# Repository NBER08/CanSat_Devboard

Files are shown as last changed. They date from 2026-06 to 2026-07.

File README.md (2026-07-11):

<p align="center" width="100%">
  
</p>

<h1 align="center">CanSat Devboard</h1>

<p align="center" width="100%">
  <a href="https://github.com/nguyen-v/KDT_Hierarchical_KiBot/actions/workflows/ci.yaml">
    
  </a>
</p>

<p align="center" width="100%">
    
</p>

***

<p align="center">
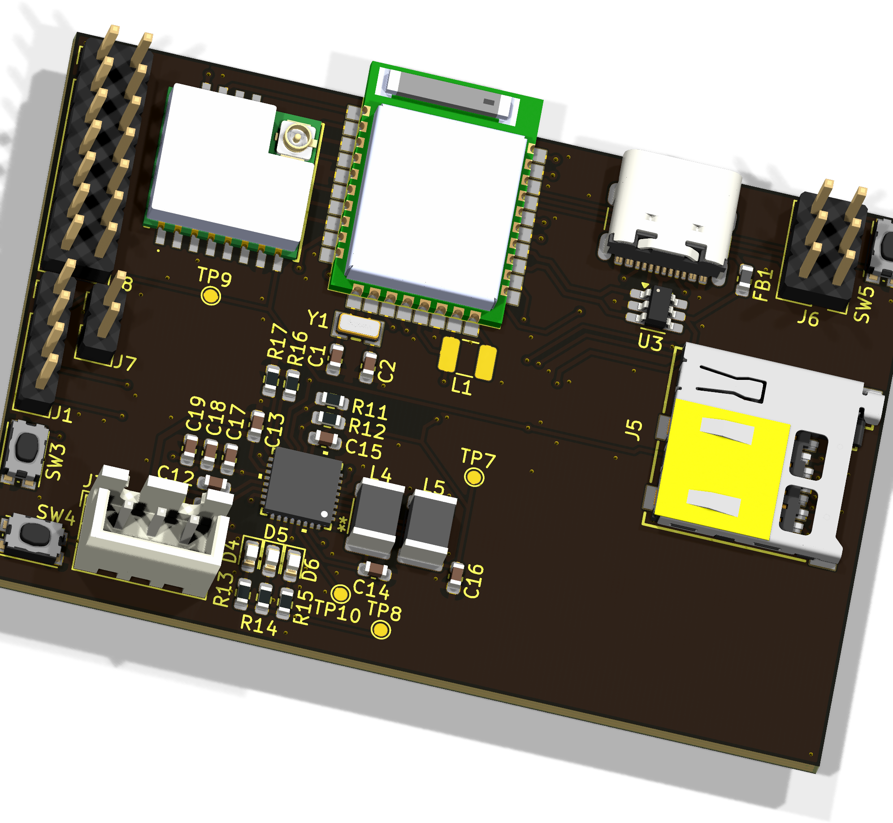
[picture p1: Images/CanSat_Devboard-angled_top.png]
3D Top Angled
  
&nbsp; &nbsp; &nbsp; &nbsp;
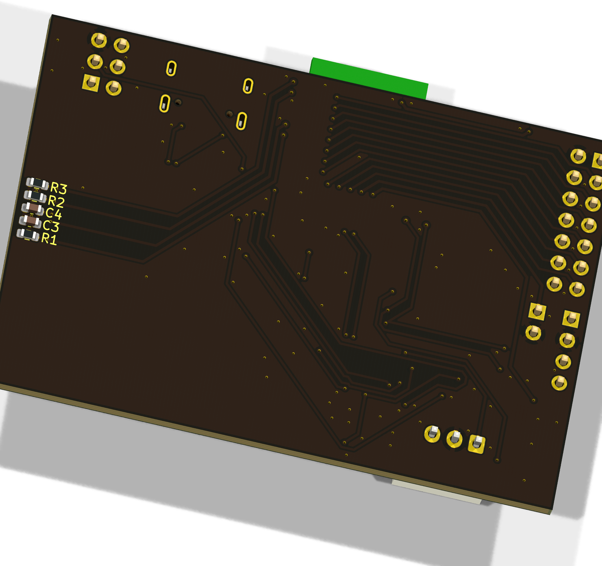
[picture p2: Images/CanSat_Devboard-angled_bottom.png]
3D Bottom Angled
  
</p>

***

## SPECIFICATIONS

| Parameter | Value | 
| --- | --- |
| Dimensions | 64.06 × 43.56 mm |

***

## DIRECTORY STRUCTURE

    .
    ├─ Computations       # Misc calculations
    ├─ HTML               # HTML files for generated webpage
    ├─ Images             # Pictures and renders
    │
    ├─ kibot_resources    # External resources for KiBot
    │  ├─ colors          # Color theme for KiCad
    │  ├─ fonts           # Fonts used in the project
    │  ├─ scripts         # External scripts used with KiBot
    │  └─ templates       # Templates for KiBot generated reports
    │
    ├─ kibot_yaml         # KiBot YAML config files
    ├─ KiRI               # KiRI (PCB diff viewer) files
    │
    ├─ lib                # KiCad footprint and symbol libraries
    │  ├─ 3d_models       # Component 3D models
    │  ├─ lib_fp          # Footprint libraries
    │  └─ lib_sym         # Symbol libraries
    │
    ├─ Logos              # Logos
    │
    ├─ Manufacturing      # Assembly and fabrication documents
    │  ├─ Assembly        # Assembly documents (BoM, pos, notes)
    │  │
    │  └─ Fabrication     # Fabrication documents (ZIP, notes)
    │     ├─ Drill Tables # CSV drill tables
    │     └─ Gerbers      # Gerbers
    │
    ├─ Report             # Reports for ERC/DRC
    ├─ Schematic          # PDF of schematic
    ├─ Templates          # Title block templates
    ├─ Testing
    │  └─ Testpoints      # Testpoints tables      
    │
    └─ Variants           # Outputs for assembly variants

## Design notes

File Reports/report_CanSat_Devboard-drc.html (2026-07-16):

Logo

(https://github.com/INTI-CMNB/KiBot/) | DRC report for CanSat_Devboard
| PCB: CanSat_Devboard Revision: + (Unreleased) Date: 2026-07-16T17:37:52 KiCad Version: 10.0.4 | Errors: 0 Warnings: 0 (+4 excluded) Total: 0 (+4 excluded)

✔

Violations

Type | Description | Details
lib_footprint_mismatch | Footprint 'USB_C_Receptacle_GCT_USB4105-xx-A_16P_TopMnt_Horizontal' does not match copy in library 'Connector_USB' | @(162.7248 mm, 81.5314 mm): Footprint J4
silk_edge_clearance | Silkscreen clipped by board edge | @(116.9794 mm, 77.3912 mm): Rectangle on Edge.Cuts @(138.775 mm, 74.3174 mm): Segment of U1 on F.Silkscreen
silk_edge_clearance | Silkscreen clipped by board edge | @(116.9794 mm, 77.3912 mm): Rectangle on Edge.Cuts @(151.775 mm, 92.8174 mm): Segment of U1 on F.Silkscreen

Schematic parity

Type | Description | Details
net_conflict | No pad found for pin S1 (GND) in schematic | @(162.7248 mm, 81.5314 mm): Footprint J4

Generated by KiBot (https://github.com/INTI-CMNB/KiBot/) v1.9.1

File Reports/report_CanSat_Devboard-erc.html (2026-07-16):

Logo

(https://github.com/INTI-CMNB/KiBot/) | ERC report for CanSat_Devboard
| Schematic: CanSat_Devboard Revision: + (Unreleased) Date: 2026-07-16T17:37:47 KiCad Version: 10.0.4 | Errors: 0 Warnings: 4 (+2 excluded) Total: 4 (+2 excluded)

Sheet / (CanSat_Devboard.kicad_sch)

Type | Description | Details
footprint_link_issues | The current configuration does not include the footprint library 'E73-2G4M08S1C' | @(0.508 mm, 1.4224 mm): Symbol U1 [E73-2G4M08S1C]
footprint_link_issues | The current configuration does not include the footprint library 'E73-2G4M08S1C' | @(0.5588 mm, 0.9017 mm): Symbol U1 [E73-2G4M08S1C]
footprint_link_issues | The current configuration does not include the footprint library 'E73-2G4M08S1C' | @(1.5113 mm, 0.6858 mm): Symbol U1 [E73-2G4M08S1C]
lib_symbol_mismatch | Symbol doesn't match copy in library | @(1.143 mm, 0.9652 mm): Symbol J4 [USB_C_Receptacle_USB2.0_16P]

Sheet /Project Architecture/Power/ (Power.kicad_sch)

Type | Description | Details
multiple_net_names | Both VSYS and PVDD are attached to the same items; VSYS will be used in the netlist | @(1.2065 mm, 1.3462 mm): Symbol #PWR063 Pin 1 [Power input, Line] @(0.6096 mm, 1.0922 mm): Label 'PVDD'
multiple_net_names | More than one name given to this bus or net | @(2.2352 mm, 0.7366 mm): Symbol #PWR056 Pin 1 [Power input, Line] @(0.6096 mm, 1.0922 mm): Label 'PVDD'

Generated by KiBot (https://github.com/INTI-CMNB/KiBot/) v1.9.1

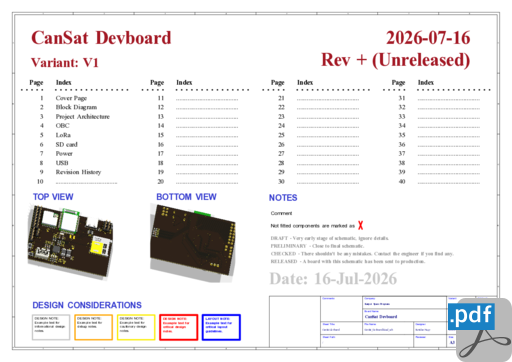
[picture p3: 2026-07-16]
HTML/images/cat_pdf_schematic_CanSat_Devboard-schematic.png

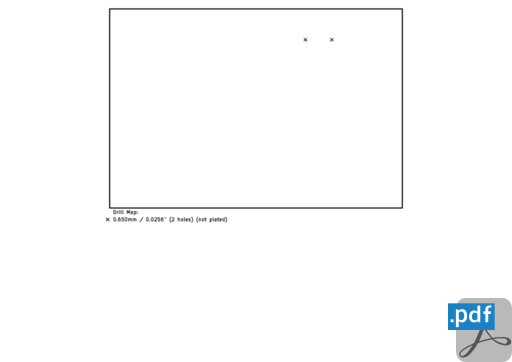
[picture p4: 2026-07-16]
HTML/images/cat_pdf_drill_map_CanSat_Devboard-NPTH_drill_map.png

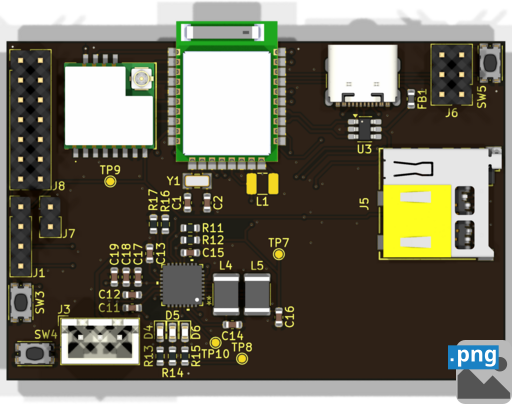
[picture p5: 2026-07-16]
HTML/images/cat_png_3d_viewer_top_CanSat_Devboard-top.png

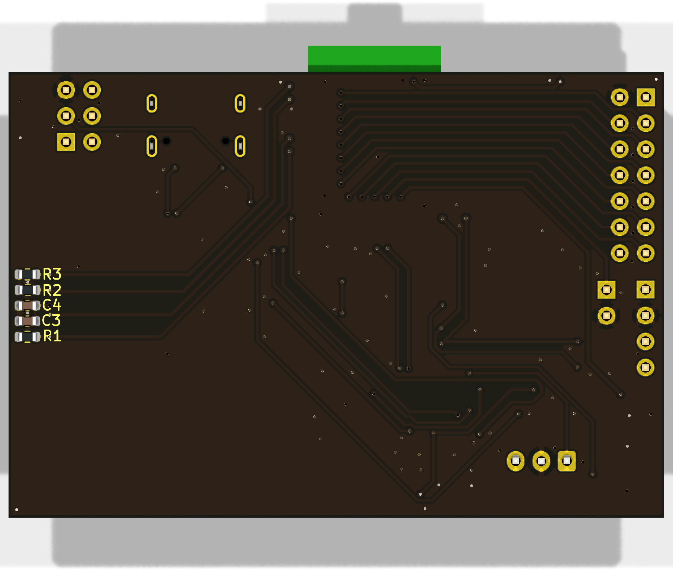
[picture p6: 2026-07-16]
Images/CanSat_Devboard-bottom.png

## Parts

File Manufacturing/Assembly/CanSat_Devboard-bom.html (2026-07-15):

 | Bill of Materials
 | Schematic: CanSat_Devboard Variant: CHECKED Revision: + (Unreleased) Date: 2026-07-05 KiCad Version: 10.0.4-10.0.4~ubuntu25.10.1 | Component Groups: 24 Component Count: 44 (per PCB) Fitted Components: 44 (per PCB) Number of PCBs: 1 Total Components: 44 (for 1 PCBs)
Row | Quantity Per PCB | References | Value | Datasheet | Footprint | Description | Manufacturer | Manufacturer Part Number | Supplier Part Number
1 | 2 | C1 C2 | 22p |  | C_0603_1608Metric | Unpolarized capacitor
2 | 2 | C3 C15 | 0.1u |  | C_0603_1608Metric | Unpolarized capacitor
3 | 2 | C11 C12 | 1u |  | C_0603_1608Metric | Unpolarized capacitor
4 | 3 | C13 L4 L5 | 2u2 |  | C_0603_1608Metric | Unpolarized capacitor Inductor, small symbol
5 | 6 | C4 C14 C16 C17 C18 C19 | 10u |  | C_0603_1608Metric | Unpolarized capacitor
6 | 1 | D4 | Amber |  | LED_0603_1608Metric | Light emitting diode, small symbol
7 | 1 | D6 | Blue |  | LED_0603_1608Metric | Light emitting diode, small symbol
8 | 1 | D5 | Green |  | LED_0603_1608Metric | Light emitting diode, small symbol
9 | 1 | FB1 | LI0603G121R-10 |  | L_0603_1608Metric | Ferrite bead
10 | 1 | IC1 | 114993390 |  | 114993390 | RF Modules Wio-SX1262 Wireless Module (Bulk), SX1262 embedded, supports LoRa&LoRaWAN on EU868 & US915
11 | 1 | J5 | 693071010811 |  | 693071010811 | 693 Series, Header for use with Micro SD Card | Wurth Electronics 693071010811
12 | 6 | J1 J3 J4 J6 J7 J8 | I2C |  | PinHeader_1x04_P2.54mm_Vertical | Generic connector, single row, 01x04, script generated Generic connector, single row, 01x03, script generated USB 2.0-only 16P Type-C Receptacle connector Generic connector, single row, 01x02, script generated Generic connector, double row, 02x07, odd/even pin numbering scheme (row 1 odd numbers, row 2 even numbers), script generated (kicad-library-utils/schlib/autogen/connector/)
13 | 2 | R14 R15 | 180 |  | R_0603_1608Metric | Resistor, small symbol
14 | 1 | R13 | 310 |  | R_0603_1608Metric | Resistor, small symbol
15 | 2 | R11 R12 | 4k7 |  | R_0603_1608Metric | Resistor
16 | 4 | R1 R2 R3 R17 | 47k |  | R_0603_1608Metric | Resistor
17 | 1 | R16 | 150k |  | R_0603_1608Metric | Resistor
18 | 1 | SW5 | RST |  | SW_Push_1P1T_NO_CK_KMR2 | Push button switch, generic, two pins
19 | 1 | SW4 | SHPHLD |  | SW_Push_1P1T_NO_CK_KMR2 | Push button switch, generic, two pins
20 | 1 | SW3 | SW_Push |  | SW_Push_1P1T_NO_CK_KMR2 | Push button switch, generic, two pins
21 | 1 | U1 | E73-2G4M08S1C |  | E73-2G4M08S1C | nRF52840 2.4GHZ SMD Wireless Module
22 | 1 | U4 | NPM1300-QEAA-R7 | https://docs.nordicsemi.com/viewer/book-attachment/kL6EnWEP1WN7P3ZfxvlurA/GH9B8FbYdmCpdjRokvIB_w-kL6EnWEP1WN7P3ZfxvlurA | QFN32_5X5_NOR
23 | 1 | U3 | SRV05-4 | http://www.onsemi.com/pub/Collateral/SRV05-4-D.PDF | SOT-23-6_Handsoldering | ESD Protection Diodes with Low Clamping Voltage, SOT-23-6
24 | 1 | Y1 | 32.768 |  | WE-XTAL_CFPX-217 | 32.768 kHz ±20ppm Crystal 12.5pF 70 kOhms 2-SMD, No Lead
Color reference for columns:
KiCad Fields (default)
Generated Fields
User Fields
Empty Fields

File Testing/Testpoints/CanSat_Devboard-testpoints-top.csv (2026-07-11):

Ref. | Net | X [mm] | Y [mm]
TP7 | VMCU | 87.96 | 1.25
TP8 | VSYS | 83.23 | -12.16
TP9 | +3.3V | 66.31 | 10.60
TP10 | VLDO | 79.83 | -10.12

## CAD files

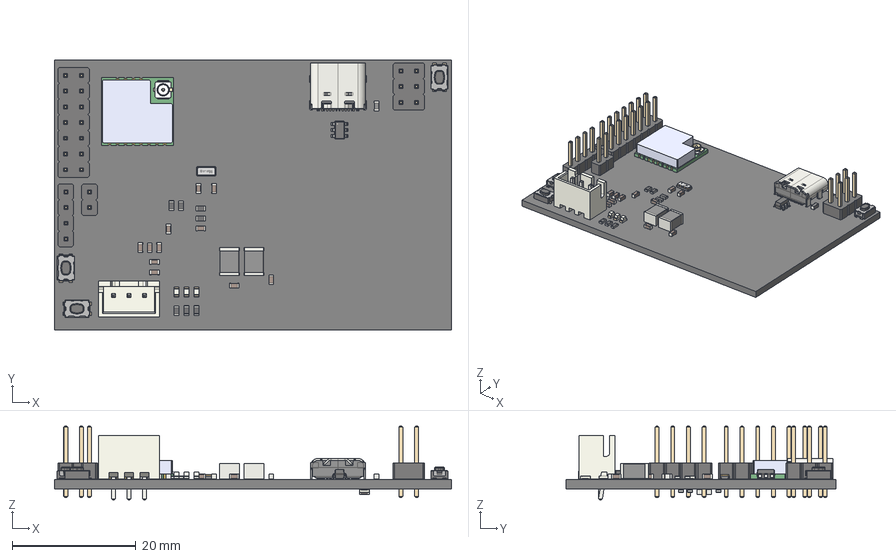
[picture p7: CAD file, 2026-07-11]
3D/CanSat_Devboard.step
64.1 x 43.6 x 11.9 mm
Pins
Cover
L_1812_4532Metric x 2
C_0603_1608Metric x 13
R_0603_1608Metric x 10
SOT-23-6
PinHeader_2x07_P254mm_Vertical
USB_C_Receptacle_16P_TopMnt_Horizontal_GCT_USB4105-xx-A
User_Library-IPEX
Extruded
LED_0603_1608Metric x 3
JST_B3B_XH_A
L_0603_1608Metric
SW_Push_1P1T_NO_CK_KMR2 x 3
PinHeader_1x04_P254mm_Vertical
PinHeader_1x02_P254mm_Vertical
PinHeader_2x03_P254mm_Vertical
kibot_y3b886p5_PCB

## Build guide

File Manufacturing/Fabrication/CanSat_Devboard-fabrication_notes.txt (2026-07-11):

FABRICATION NOTES (UNLESS OTHERWISE SPECIFIED)

1)	FABRICATE PER IPC-6012A CLASS 2.

2)	OUTLINE DEFINED IN SEPARATE GERBER FILE WITH
	"Edge_Cuts.GBR" SUFFIX.

	DIMENSIONS OF CIRCUMSIZED RECTANGLE SHOWN ON THIS
	DRAWING FOR REFERENCE ONLY.

3)	SEE SEPARATE DRILL FILES WITH ".DRL" SUFFIX 
	FOR HOLE LOCATIONS.

	SELECTED HOLE LOCATIONS SHOWN ON THIS DRAWING 
	FOR REFERENCE ONLY.

4)	SURFACE FINISH: IMMERSION GOLD

5)	SOLDERMASK ON BOTH SIDES OF THE BOARD SHALL 
	BE LPI, COLOR BLACK.

6)	SILK SCREEN LEGEND TO BE APPLIED PER LAYER 
	STACKUP USING YELLOW NON-CONDUCTIVE EPOXY INK.

7)	ALL VIAS ARE TENTED ON BOTH SIDES UNLESS 
	SOLDERMASK OPENED IN GERBER.

8)	VENDOR SHOULD FOLLOW ROHS COMPLIANT PROCESS 
	AND Pb FREE FOR MANUFACTURING

9)	PCB MATERIAL REQUIREMENTS:

	A.	FLAMMABILITY RATING MUST MEET OR EXCEED 
		UL94V-0 REQUIREMENTS.
	B.	Tg 170 C OR EQUIVALENT.
	C.	EQUIVALENT MATERIAL SHALL BE RoHS COMPLIANT, 
		HALOGEN FREE AND APPROVED BY KARPAT SPACE PROGRAM.

10)	DESIGN GEOMETRY MINIMUM FEATURE SIZES:

	BOARD SIZE				64.059 × 43.561 mm
	BOARD THICKNESS		1.660 mm
	TRACE WIDTH			0.200 mm
	TRACE TO TRACE		0.200 mm
	MIN. HOLE (PTH)			0.250 mm
	MIN. HOLE (NPTH)		0.650 mm
	ANNULAR RING			0.150 mm
	COPPER TO HOLE		0.250 mm
	COPPER TO EDGE		0.250 mm
	HOLE TO HOLE			0.100 mm

11)	REFER TO IMPEDANCE TABLE FOR IMPEDANCE CONTROL REQUIREMENTS.

12)	CONFIRM SPACE WIDTHS AND SPACINGS.

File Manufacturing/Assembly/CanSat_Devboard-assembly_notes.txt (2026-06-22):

ASSEMBLY NOTES (UNLESS OTHERWISE SPECIFIED)

1)	DO NOT POPULATE PARTS ARE MARKED WITH A RED CROSS.

2)	DO NOT POPULATE PARTS ARE NOT PRESENT IN THE BOM.

3)	IF CONFLICTING INFORMATION IS FOUND BETWEEN THE ASSEMBLY
	FILE AND BOM, BOM SHOULD BE USED AS THE MAIN SOURCE.

4)	CONFORMAL COATING IS NOT REQUIRED.

5)	DOT IDENTIFIES PIN #1 LOCATION AND DEVICE ORIENTATION
	WHEN VIEWED FROM THE TOP.

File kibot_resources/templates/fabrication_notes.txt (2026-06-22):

FABRICATION NOTES (UNLESS OTHERWISE SPECIFIED)

1)	FABRICATE PER IPC-6012A CLASS 2.

2)	OUTLINE DEFINED IN SEPARATE GERBER FILE WITH
	"Edge_Cuts.GBR" SUFFIX.

	DIMENSIONS OF CIRCUMSIZED RECTANGLE SHOWN ON THIS
	DRAWING FOR REFERENCE ONLY.

3)	SEE SEPARATE DRILL FILES WITH ".DRL" SUFFIX 
	FOR HOLE LOCATIONS.

	SELECTED HOLE LOCATIONS SHOWN ON THIS DRAWING 
	FOR REFERENCE ONLY.

4)	SURFACE FINISH: ${pcb_finish_cap}

5)	SOLDERMASK ON BOTH SIDES OF THE BOARD SHALL 
	BE LPI, COLOR ${solder_mask_color_text_cap}.

6)	SILK SCREEN LEGEND TO BE APPLIED PER LAYER 
	STACKUP USING ${silk_screen_color_text_cap} NON-CONDUCTIVE EPOXY INK.

7)	ALL VIAS ARE TENTED ON BOTH SIDES UNLESS 
	SOLDERMASK OPENED IN GERBER.

8)	VENDOR SHOULD FOLLOW ROHS COMPLIANT PROCESS 
	AND Pb FREE FOR MANUFACTURING

9)	PCB MATERIAL REQUIREMENTS:

	A.	FLAMMABILITY RATING MUST MEET OR EXCEED 
		UL94V-0 REQUIREMENTS.
	B.	Tg 170 C OR EQUIVALENT.
	C.	EQUIVALENT MATERIAL SHALL BE RoHS COMPLIANT, 
		HALOGEN FREE AND APPROVED BY ${COMPANY_cap}.

10)	DESIGN GEOMETRY MINIMUM FEATURE SIZES:

	BOARD SIZE				${bb_w_mm} × ${bb_h_mm} mm
	BOARD THICKNESS		${thickness_mm} mm
	TRACE WIDTH			${track_mm} mm
	TRACE TO TRACE		${clearance_mm} mm
	MIN. HOLE (PTH)			${drill_pth_real_mm} mm
	MIN. HOLE (NPTH)		${drill_npth_real_mm} mm
	ANNULAR RING			${oar_mm} mm
	COPPER TO HOLE		${c2h_mm} mm
	COPPER TO EDGE		${c2e_mm} mm
	HOLE TO HOLE			${h2h_mm} mm
#?stackup and impedance_controlled

#?stackup and impedance_controlled
11)	REFER TO IMPEDANCE TABLE FOR IMPEDANCE CONTROL REQUIREMENTS.
#?stackup and impedance_controlled

#?stackup and impedance_controlled
12)	CONFIRM SPACE WIDTHS AND SPACINGS.

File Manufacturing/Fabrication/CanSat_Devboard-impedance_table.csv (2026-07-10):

Transmission Line | Impedance [ohms] | Tolerance [ohms] | Layer | Trace Width [mm] | Gap [mm] | Ref. Layers
Edge-Coupled Coated Microstrip | 100 | ±10 % | L1 | 0.2032 | 0.28 | L2

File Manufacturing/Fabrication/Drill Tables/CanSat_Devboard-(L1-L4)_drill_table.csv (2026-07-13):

Count | Hole Size | Plated | Hole Shape | Drill Layer Pair | Hole Type
145 | 0.25mm (9.84mils) | PTH | Round | L1 (Sig, PWR) - L4 (Sig, PWR) | Via
6 | 0.30mm (11.81mils) | PTH | Round | L1 (Sig, PWR) - L4 (Sig, PWR) | Via
4 | 0.60mm (23.62mils) | PTH | Slot | L1 (Sig, PWR) - L4 (Sig, PWR) | Pad
3 | 0.95mm (37.40mils) | PTH | Round | L1 (Sig, PWR) - L4 (Sig, PWR) | Pad
26 | 1.00mm (39.37mils) | PTH | Round | L1 (Sig, PWR) - L4 (Sig, PWR) | Pad
Total 184

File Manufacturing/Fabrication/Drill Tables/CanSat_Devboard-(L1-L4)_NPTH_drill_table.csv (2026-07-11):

Count | Hole Size | Plated | Hole Shape | Drill Layer Pair | Hole Type
2 | 0.65mm (25.59mils) | NPTH | Round | L1 (Sig, PWR) - L4 (Sig, PWR) | Mechanical
Total 2

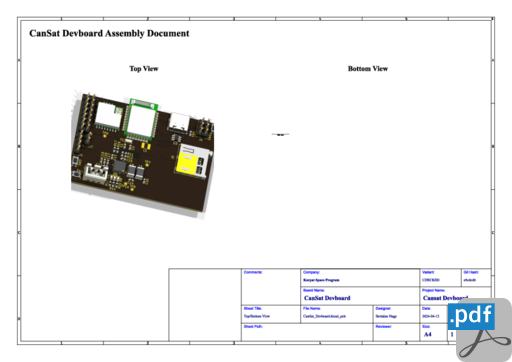
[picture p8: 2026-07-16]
HTML/images/cat_pdf_assembly_CanSat_Devboard-assembly.png

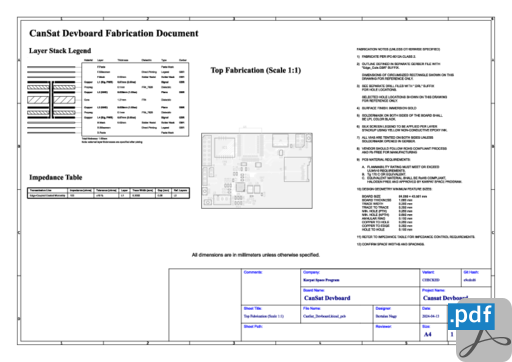
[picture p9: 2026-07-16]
HTML/images/cat_pdf_fabrication_CanSat_Devboard-fabrication.png

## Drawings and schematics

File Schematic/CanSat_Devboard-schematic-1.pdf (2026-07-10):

# CanSat Devboard

# Variant: V1

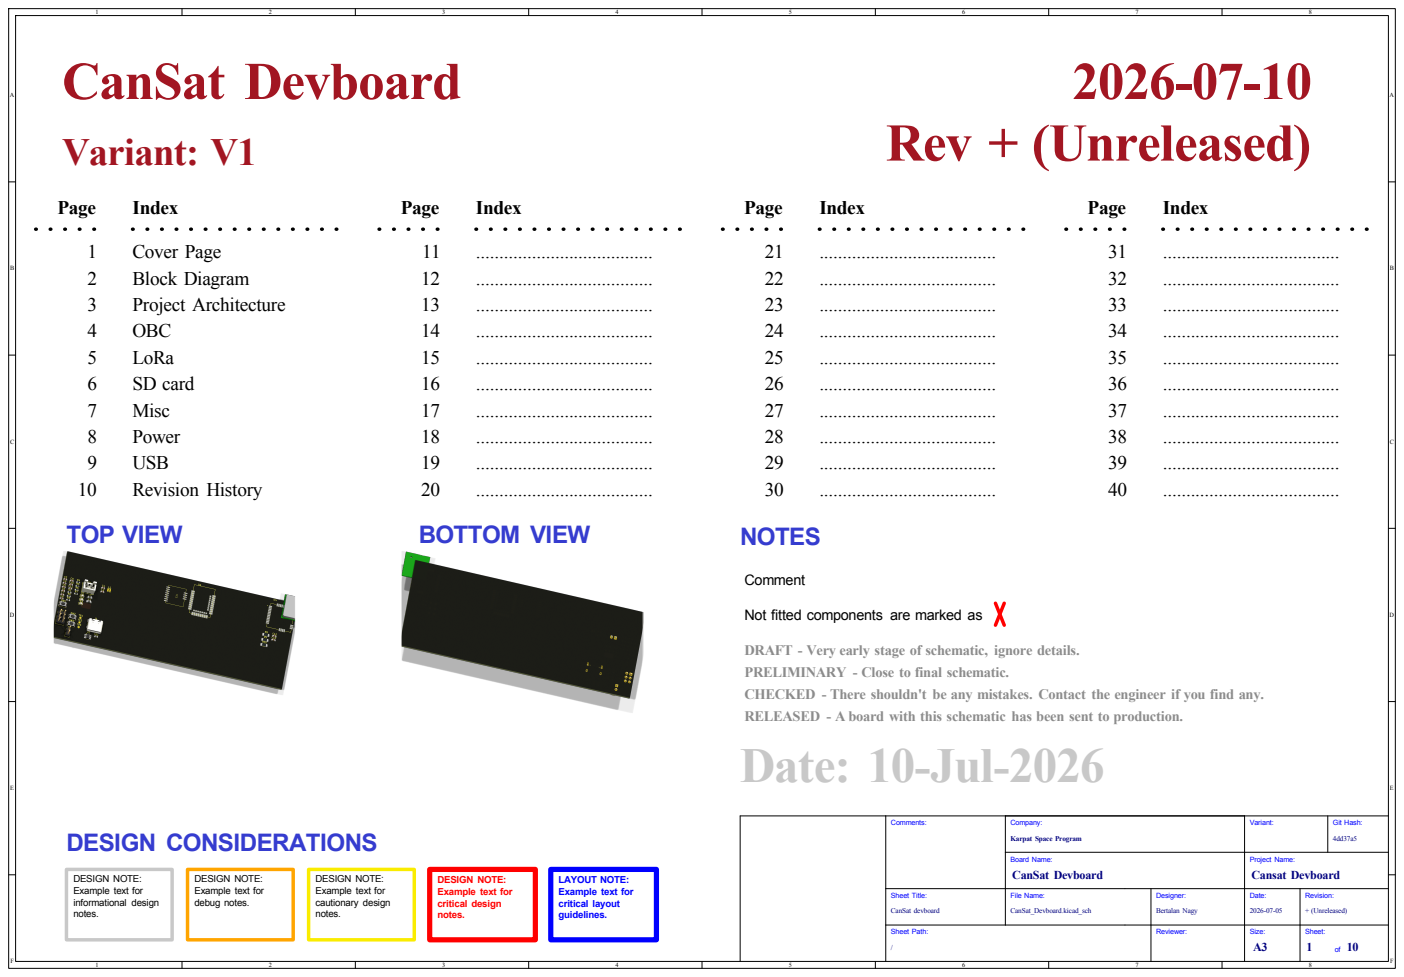
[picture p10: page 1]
Sheet: of 10; Size: A3; CanSat_Devboard.kicad_sch; Bertalan Nagy Board Name: Company:; Variant: Karpat Space Program; CanSat Devboard; Cansat Devboard; Sheet Title:; File Name:; /Sheet Path: CanSat devboard Comments:; Git Hash: 4dd37a5 Block Diagram; kibot_image_png_3d_viewer_angled_top; DESIGN NOTE:; kibot_image_png_3d_viewer_angled_bottom; LAYOUT NOTE:; Cover Page; ...................................... Index; Page; Index; TOP VIEW; BOTTOM VIEW; DESIGN CONSIDERATIONS; USB; Misc; SD card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

...................................... PRELIMINARY - Close to final schematic.

DRAFT - Very early stage of schematic, ignore details.
Date: 10-Jul-2026

CHECKED - There shouldn't be any mistakes. Contact the engineer if you find any.
RELEASED - A board with this schematic has been sent to production.

Revision: + (Unreleased) Date: Project Name: 2026-07-05 Reviewer: Designer:

DESIGN NOTE:
Example text for
informational design
notes.

debug notes.

critical design

cautionary design

critical layout
guidelines.

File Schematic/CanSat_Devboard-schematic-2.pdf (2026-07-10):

# [2] Block Diagram

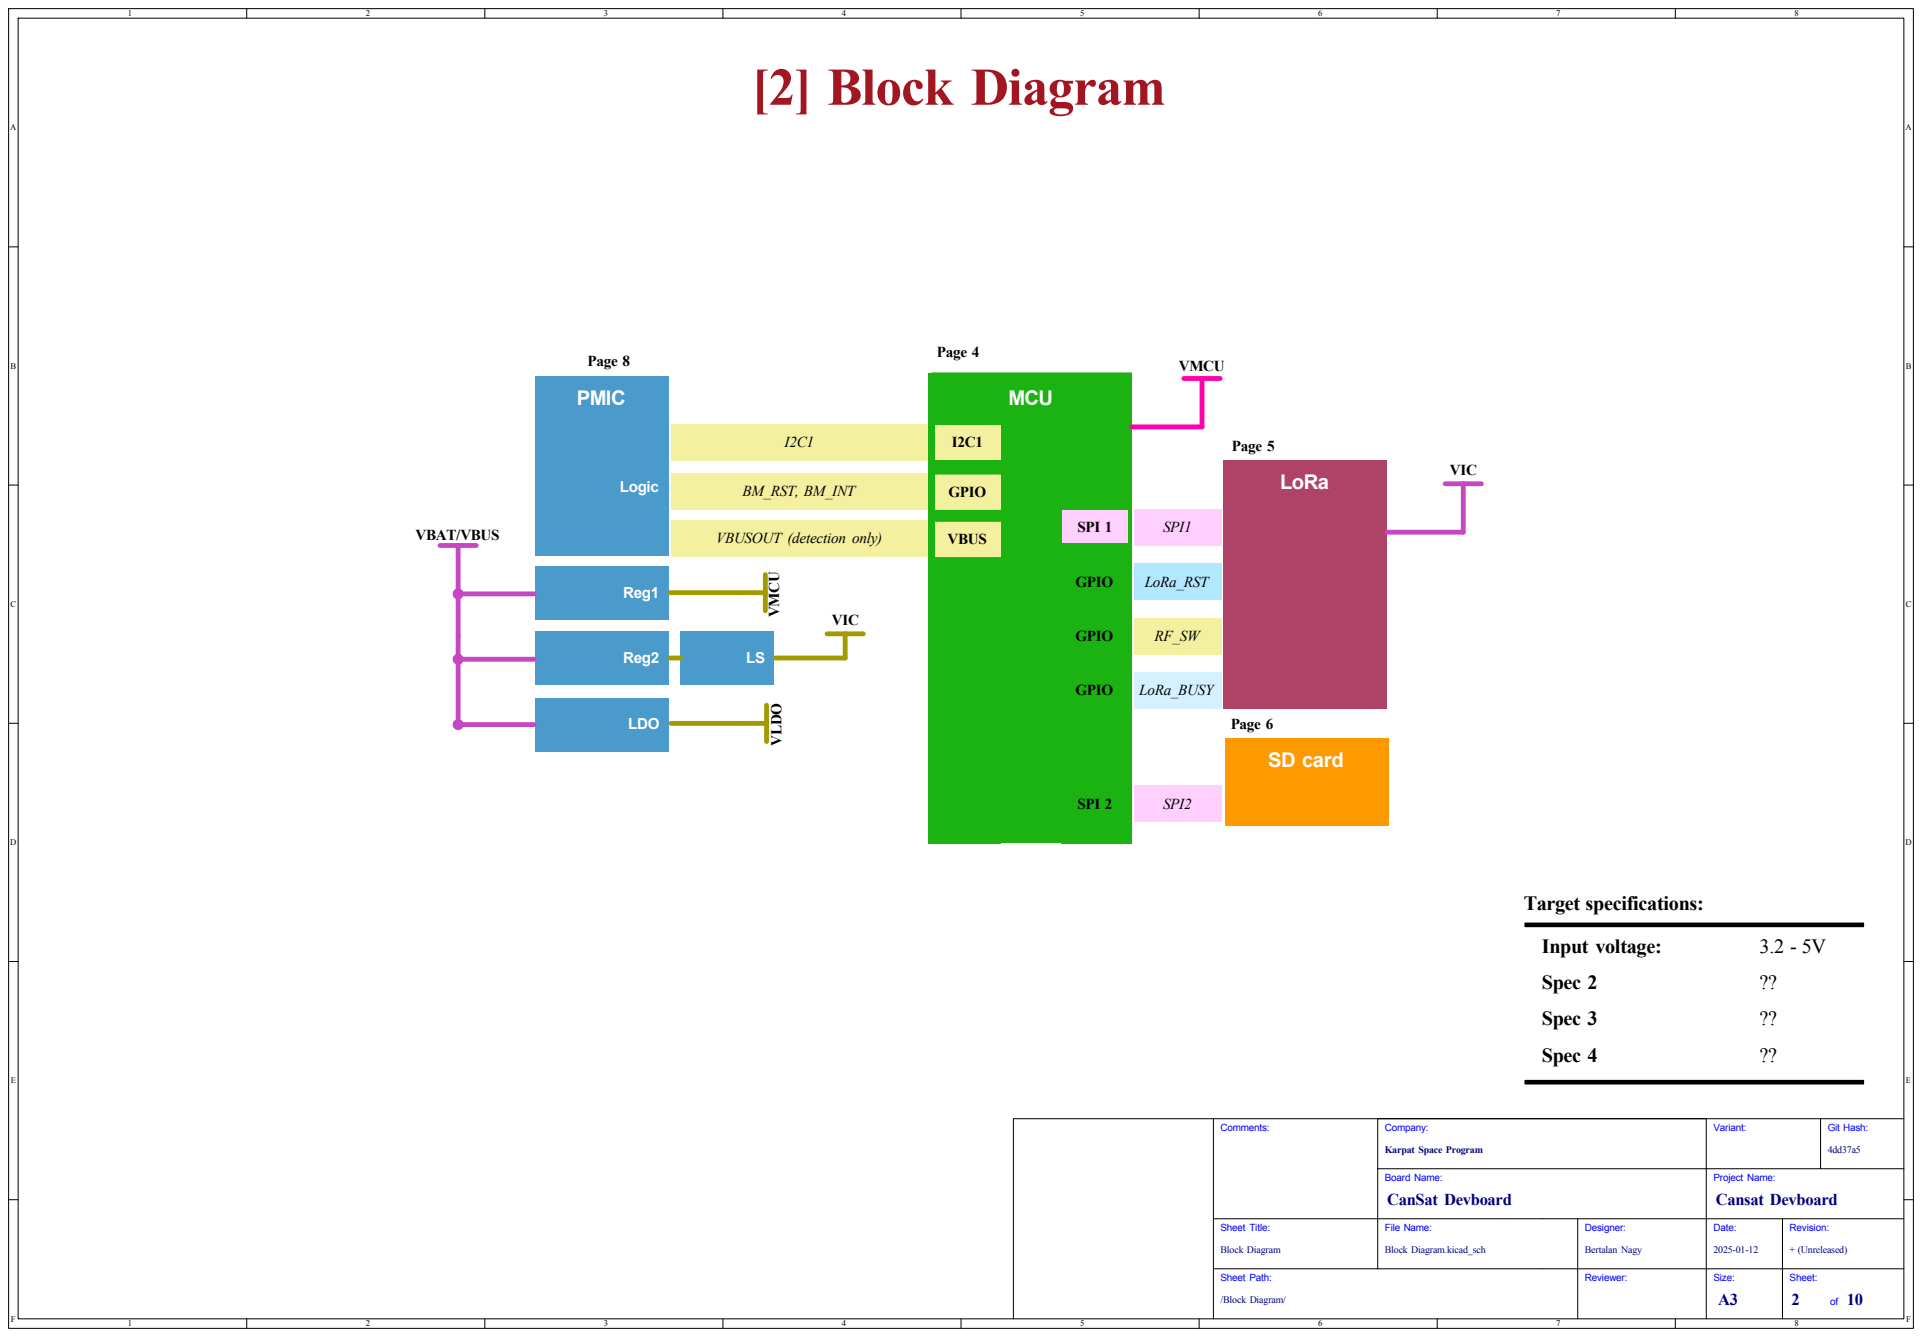
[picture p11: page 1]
Sheet: of 10; Size: A3; Revision: + (Unreleased) Date: Project Name: 2025-01-12 Reviewer: Designer: Block Diagram.kicad_sch; Bertalan Nagy Board Name: Company:; Variant: Karpat Space Program; CanSat Devboard; Cansat Devboard; Sheet Title:; File Name:; Comments:; Git Hash: 4dd37a5 Page 6; GPIO; SD card; SPI2; VBUS; SPI 2; Page 4; LoRa_RST; SPI 1; SPI1; LoRa_BUSY; BM_RST, BM_INT; MCU; Target specifications:; Logic; Page 5; LoRa; Page 8; PMIC; LDO; Reg1; Reg2; Spec 3; Spec 4; Input voltage: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

VBUSOUT (detection only)

/Block Diagram/ Sheet Path: Block Diagram

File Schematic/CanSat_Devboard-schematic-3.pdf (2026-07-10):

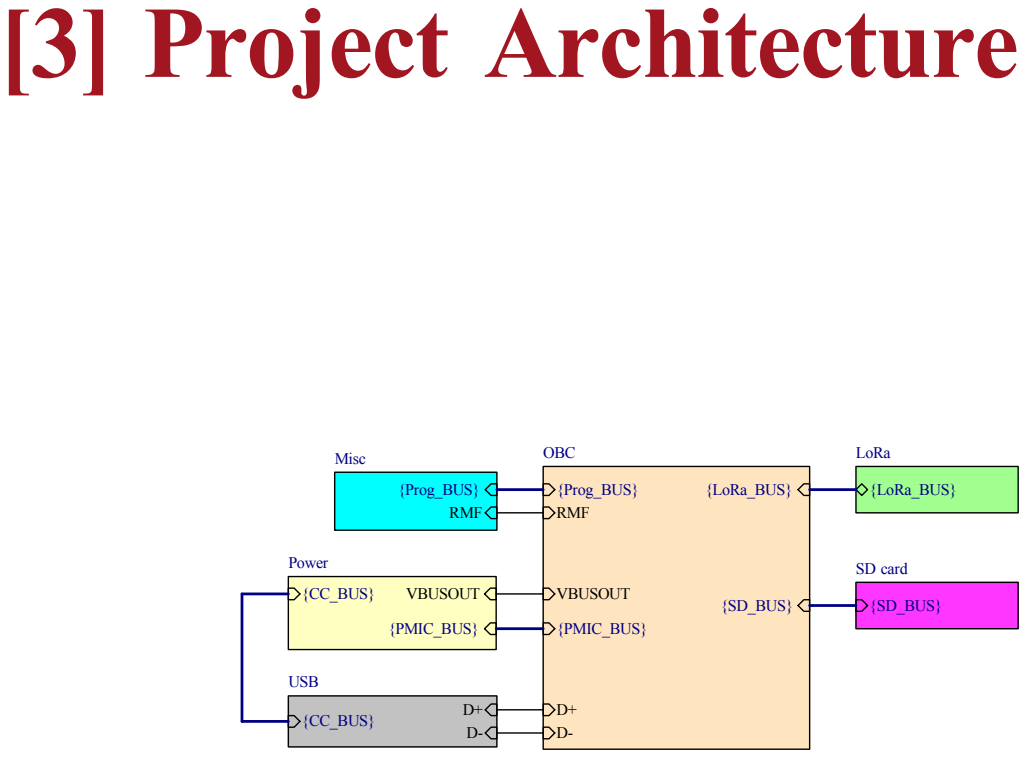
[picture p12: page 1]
Sheet: of 10; Size: A3; Project Architecture.kicad_sch; Bertalan Nagy Board Name: Company:; Variant: Karpat Space Program; CanSat Devboard; Cansat Devboard; Sheet Title:; File Name:; Comments:; Git Hash: 4dd37a5; D+D- {Prog_BUS}; {LoRa_BUS} RMF VBUSOUT; {PMIC_BUS}; {SD_BUS} OBC; {SD_BUS} SD card; {Prog_BUS} RMF Misc; D+D- {CC_BUS} USB; VBUSOUT; {CC_BUS} Power; {LoRa_BUS} LoRa [3] Project Architecture

Revision: + (Unreleased) Date: Project Name: 2025-01-12 Reviewer: Designer:

/Project Architecture/ Sheet Path: Block Diagram

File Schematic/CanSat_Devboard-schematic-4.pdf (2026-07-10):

P1.11 | 1 P1.10 | 2 P1.13 | 6 P1.09 17 P1.00 36 P1.02 38 P1.04 40 P1.06 42 U1C

# RST [4] OBC

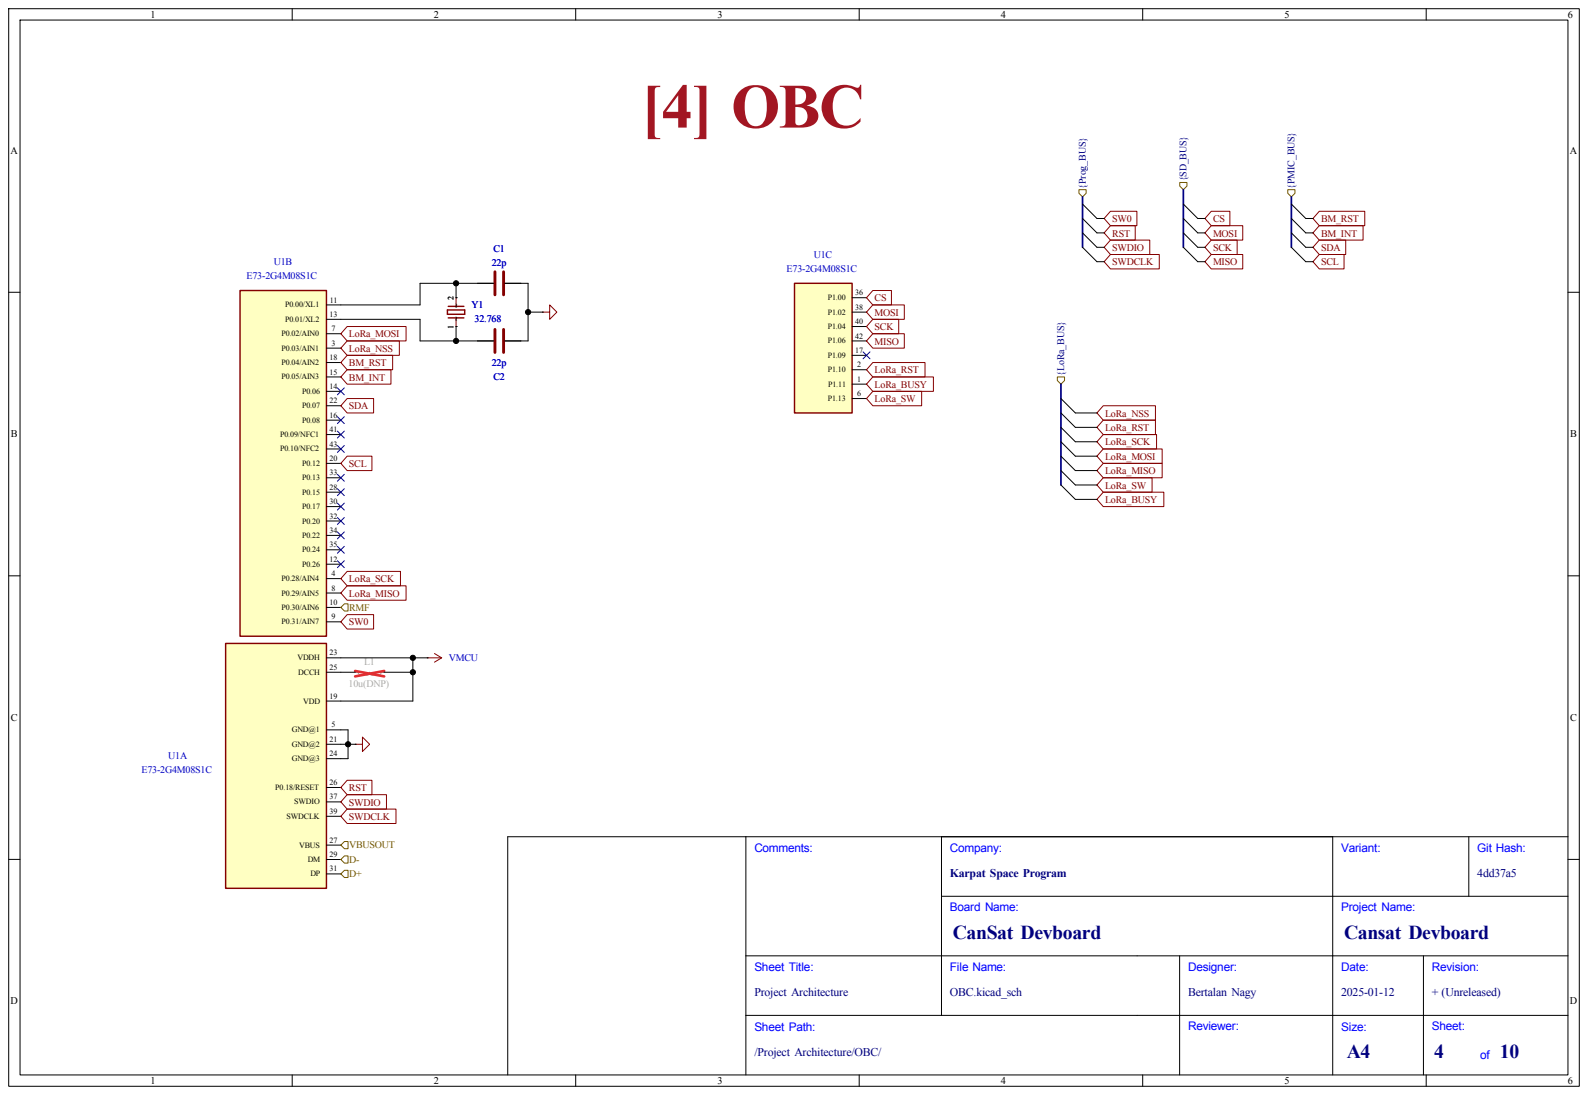
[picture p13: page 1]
6 ABCD; ABCD 4; Sheet: of 10; Size: A4; OBC.kicad_sch; Bertalan Nagy Board Name: Company:; Variant: Karpat Space Program; CanSat Devboard; Cansat Devboard; Sheet Title:; File Name:; /Project Architecture/OBC/ Sheet Path: Project Architecture Comments:; Git Hash: 4dd37a5; GND@1; 5 VDD 19 GND@2 21 VDDH 23 GND@3 24 DCCH 25 P0.18/RESET; 26 VBUS 27 DM 29 DP 31 SWDIO 37 SWDCLK 39 U1A; VMCU; 10u(DNP); P0.03/AIN1; 3 P0.28/AIN4; 4 P0.02/AIN0; 7 P0.29/AIN5; 8 P0.31/AIN7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

Revision: + (Unreleased) Date: Project Name: 2025-01-12 Reviewer: Designer:

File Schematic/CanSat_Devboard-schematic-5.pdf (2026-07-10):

# [5] LoRa

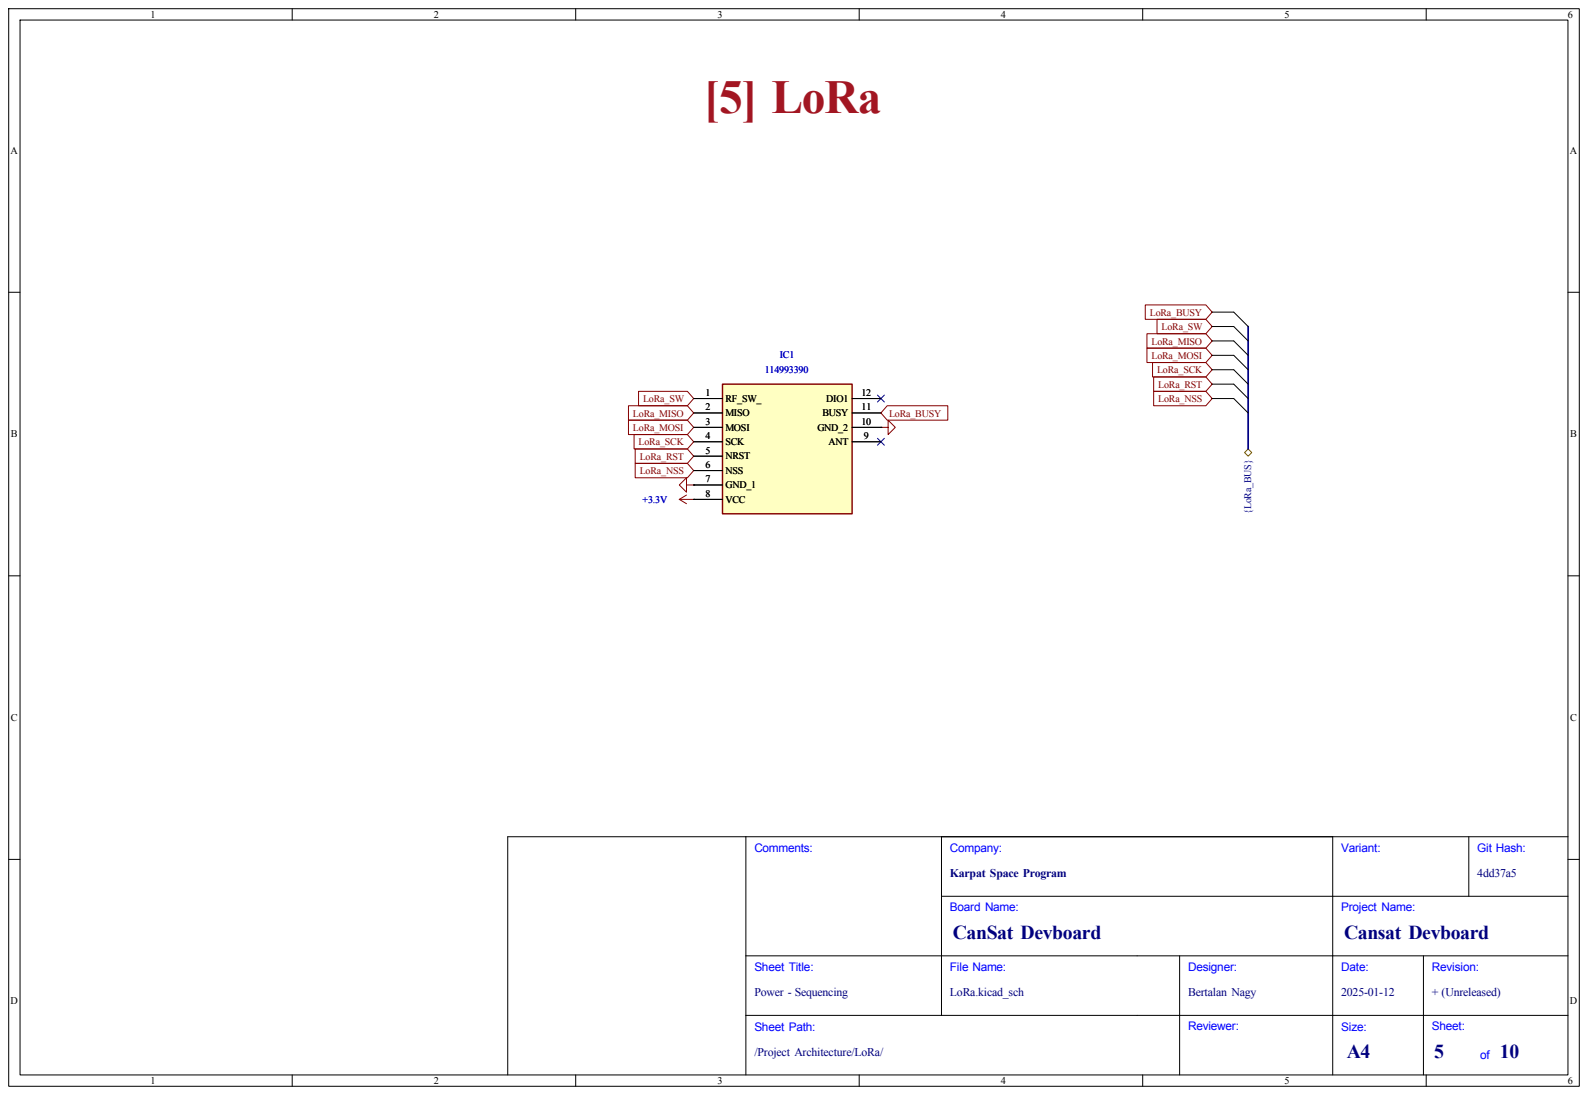
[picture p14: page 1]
Sheet: of 10; Size: A4; LoRa.kicad_sch; Bertalan Nagy Board Name: Company:; Variant: Karpat Space Program; CanSat Devboard; Cansat Devboard; Sheet Title:; File Name:; /Project Architecture/LoRa/ Sheet Path: Power - Sequencing Comments:; Git Hash: 4dd37a5; MISO 2; MOSI 3; SCK 4; NRST 5; NSS 6; GND_1 7; VCC 8; ANT; 9 GND_2; 10 BUSY; 11 DIO1 12; {LoRa_BUS}; LoRa_SW LoRa_MISO LoRa_MOSI; LoRa_BUSY; LoRa_SCK; LoRa_NSS; LoRa_RST; LoRa_MOSI; LoRa_SW; LoRa_MISO; 11 DIO1 12 +3.3V

Revision: + (Unreleased) Date: Project Name: 2025-01-12 Reviewer: Designer:

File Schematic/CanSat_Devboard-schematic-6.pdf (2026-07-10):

47k +3.3V

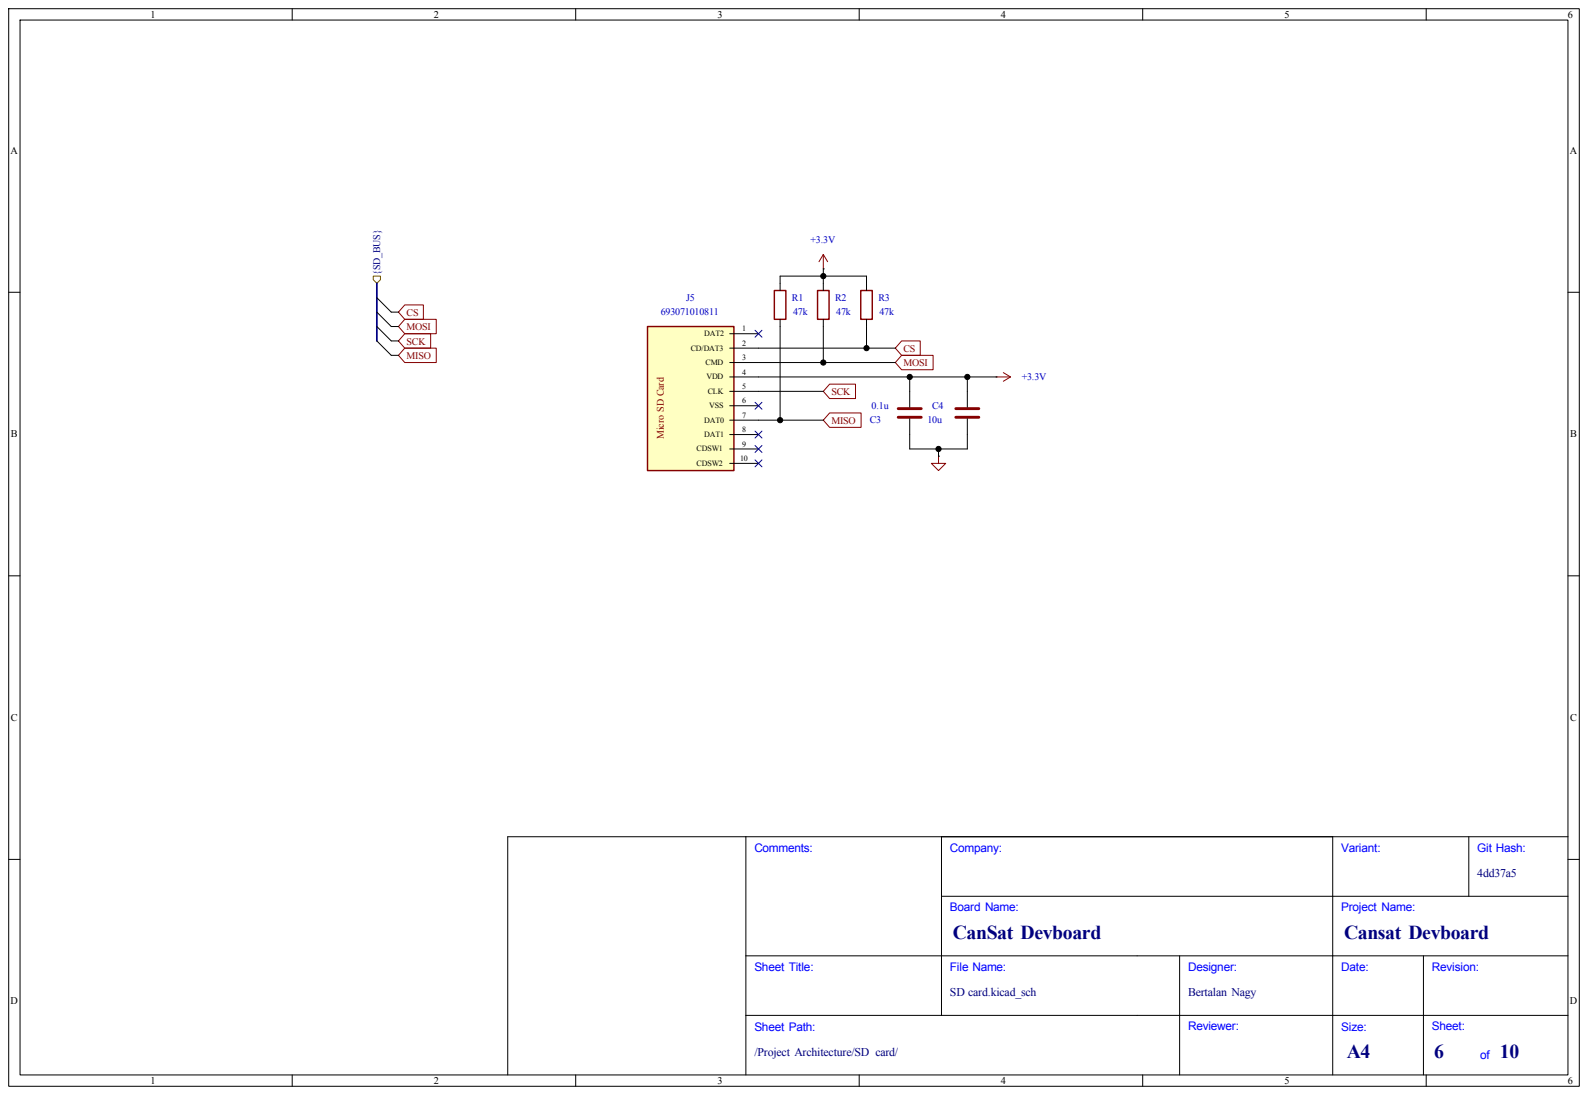
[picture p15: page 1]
Sheet: of 10; Size: A4; Date:; Revision: Project Name: Reviewer: Designer: SD card.kicad_sch; Bertalan Nagy Board Name: Company:; Variant: CanSat Devboard; Cansat Devboard; Sheet Title:; File Name:; /Project Architecture/SD card/ Sheet Path: Comments:; Git Hash: 4dd37a5; +3.3V Micro SD Card; DAT2; 1 CD/DAT3; 2 CMD; 3 VDD; 4 CLK; 5 VSS; 6 DAT0; 7 DAT1; 8 CDSW1; 9 CDSW2; 693071010811 {SD_BUS}; MISO

CSMOSI CS
SCK MISO MOSI SCK

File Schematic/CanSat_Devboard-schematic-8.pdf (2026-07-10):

# 4k7 VSYS C19

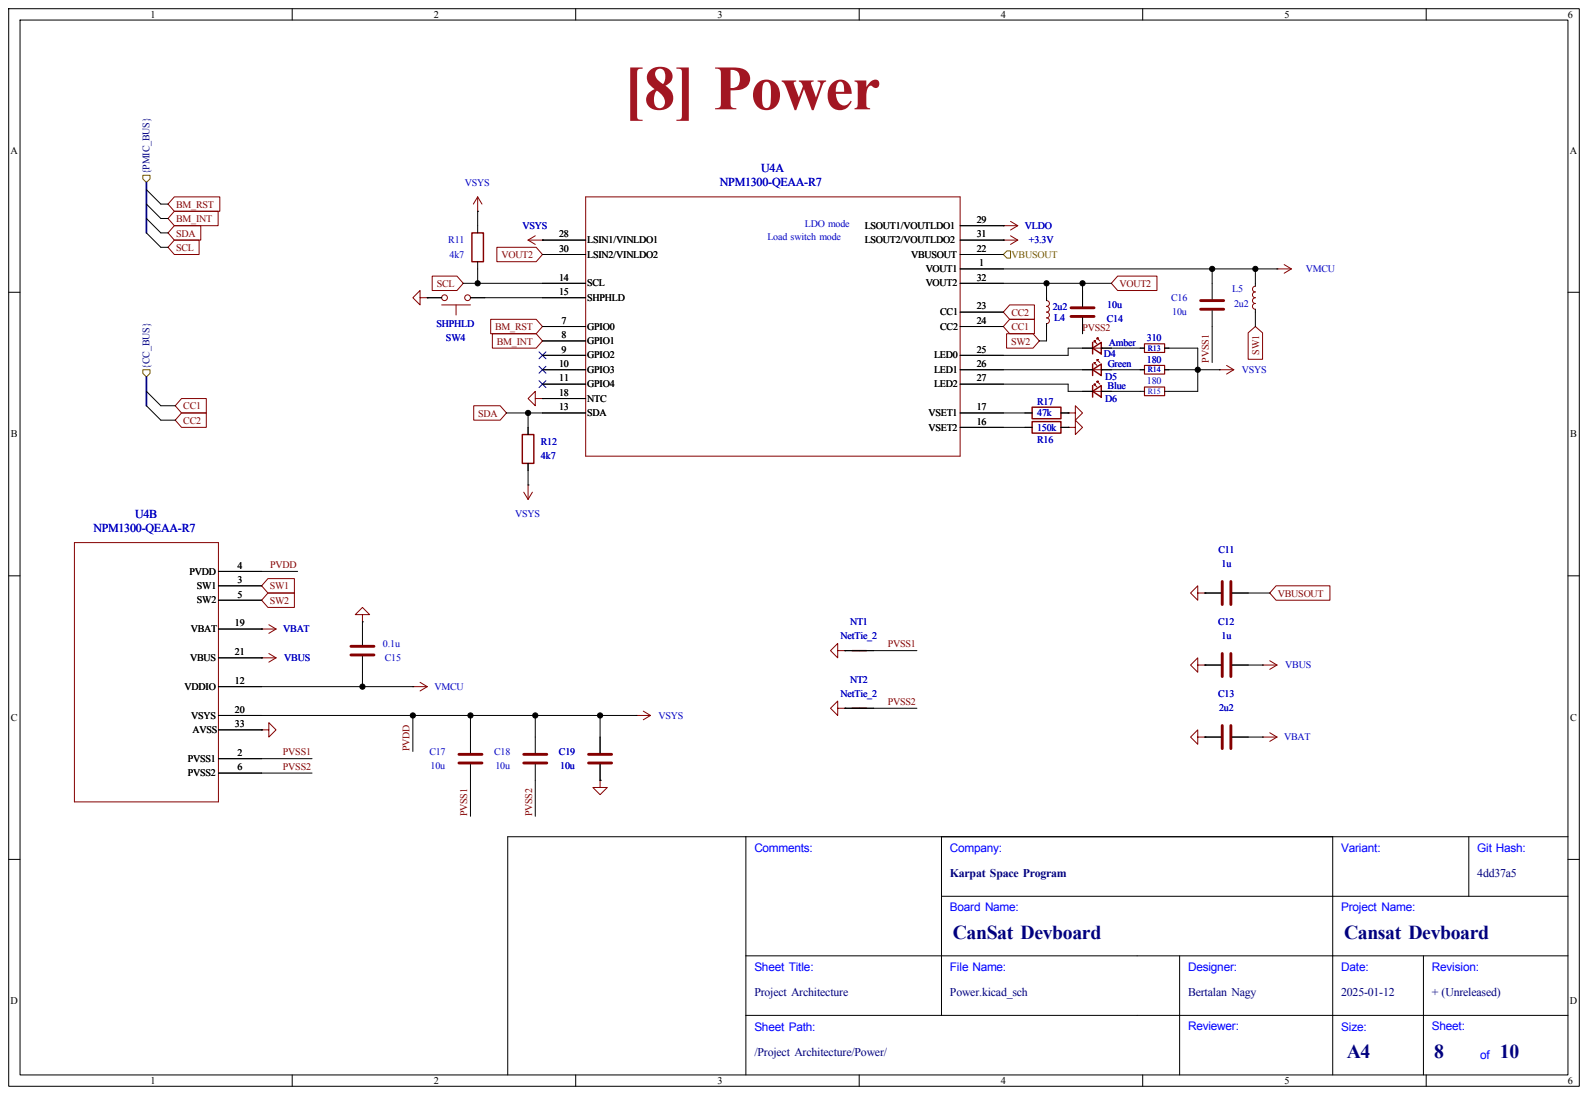
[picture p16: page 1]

LDO mode Load switch mode R12

Revision: + (Unreleased) Date: Project Name: 2025-01-12 Reviewer: Designer:

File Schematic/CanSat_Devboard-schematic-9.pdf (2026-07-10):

# [9] USB

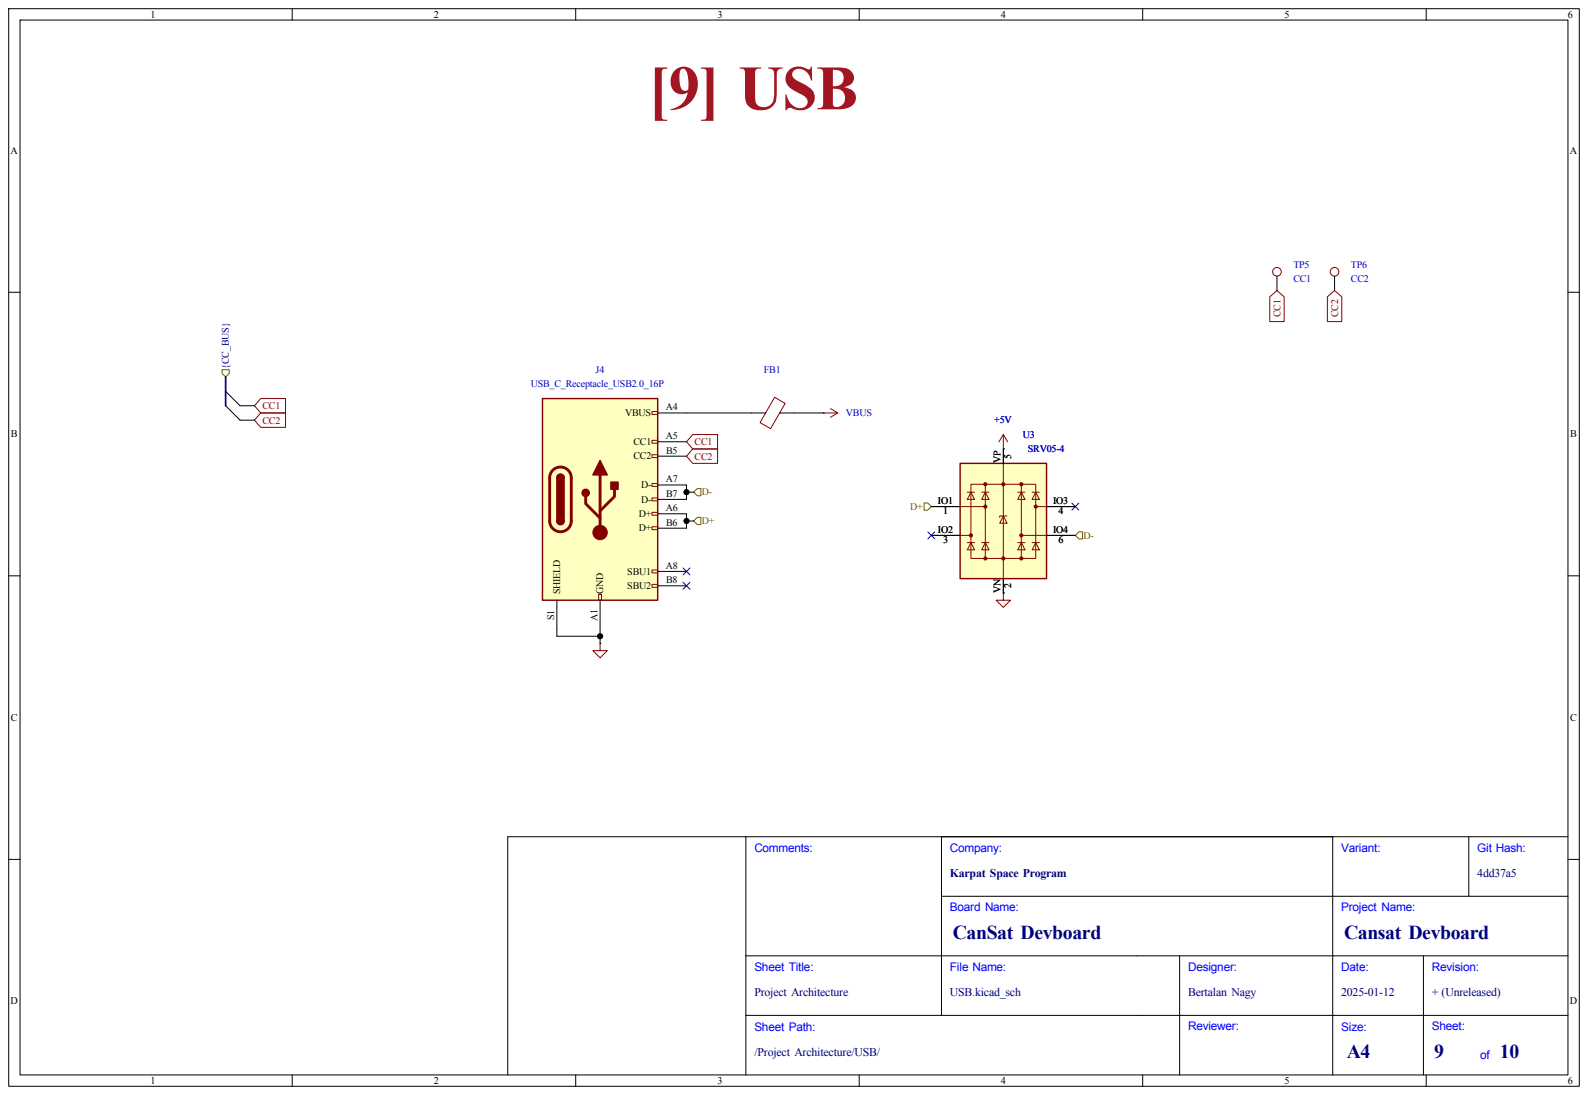
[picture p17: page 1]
Sheet: of 10; Size: A4; USB.kicad_sch; Bertalan Nagy Board Name: Company:; Variant: Karpat Space Program; CanSat Devboard; Cansat Devboard; Sheet Title:; File Name:; /Project Architecture/USB/ Sheet Path: Project Architecture Comments:; Git Hash: 4dd37a5; 6 U3SRV05-4; TP6 CC2 TP5 CC1 VBUS; +5V GND A¹; VBUS; A7 SBU1; B7 SBU2; B8 SHIELD S¹; J4 USB_C_Receptacle_USB2.0_16P {CC_BUS}; CC¹; CC²; U3SRV05-4

Revision: + (Unreleased) Date: Project Name: 2025-01-12 Reviewer: Designer:

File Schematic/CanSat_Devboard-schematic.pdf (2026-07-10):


...................................... PRELIMINARY - Close to final schematic.

DRAFT - Very early stage of schematic, ignore details.
Date: 10-Jul-2026

CHECKED - There shouldn't be any mistakes. Contact the engineer if you find any.
RELEASED - A board with this schematic has been sent to production.

Revision: + (Unreleased) Date: Project Name: 2026-07-05 Reviewer: Designer:


BM_RST, BM_INT | GPIO

SPI 1 | SPI1

/Block Diagram/ Sheet Path: Block Diagram


Revision: + (Unreleased) Date: Project Name: 2025-01-12 Reviewer: Designer:

/Project Architecture/ Sheet Path: Block Diagram

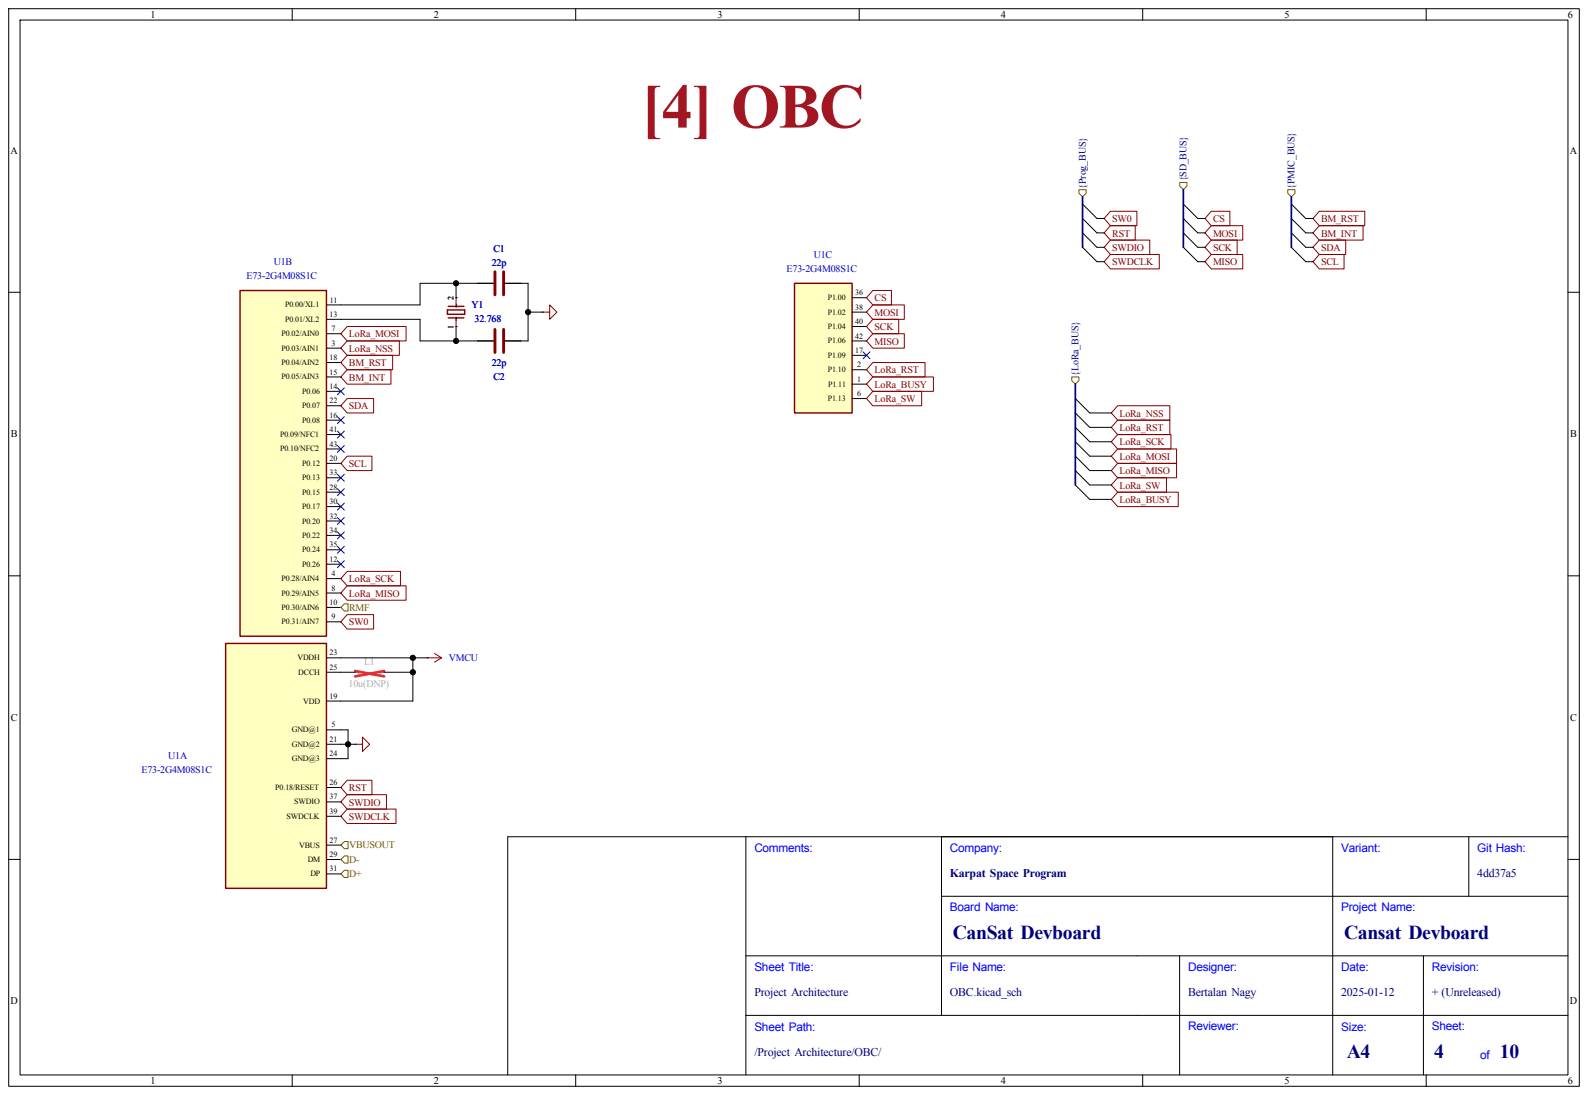
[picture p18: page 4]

Revision: + (Unreleased) Date: Project Name: 2025-01-12 Reviewer: Designer:


Revision: + (Unreleased) Date: Project Name: 2025-01-12 Reviewer: Designer:


CSMOSI CS
SCK MISO MOSI SCK

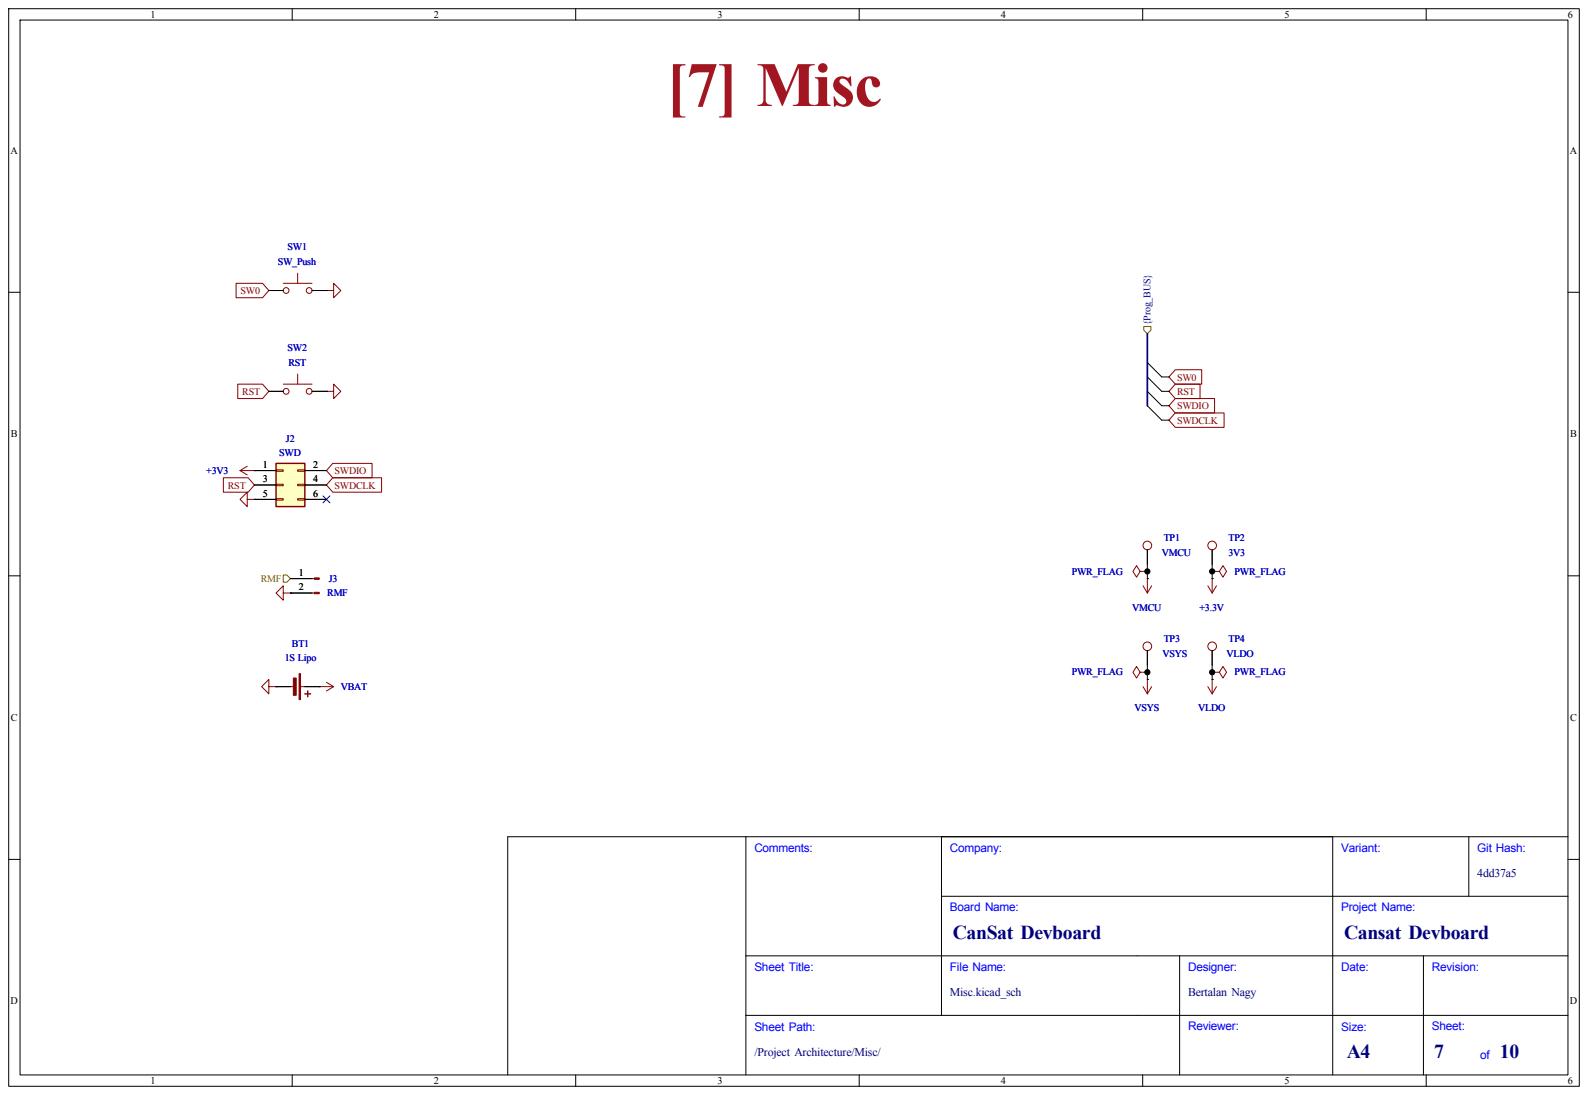
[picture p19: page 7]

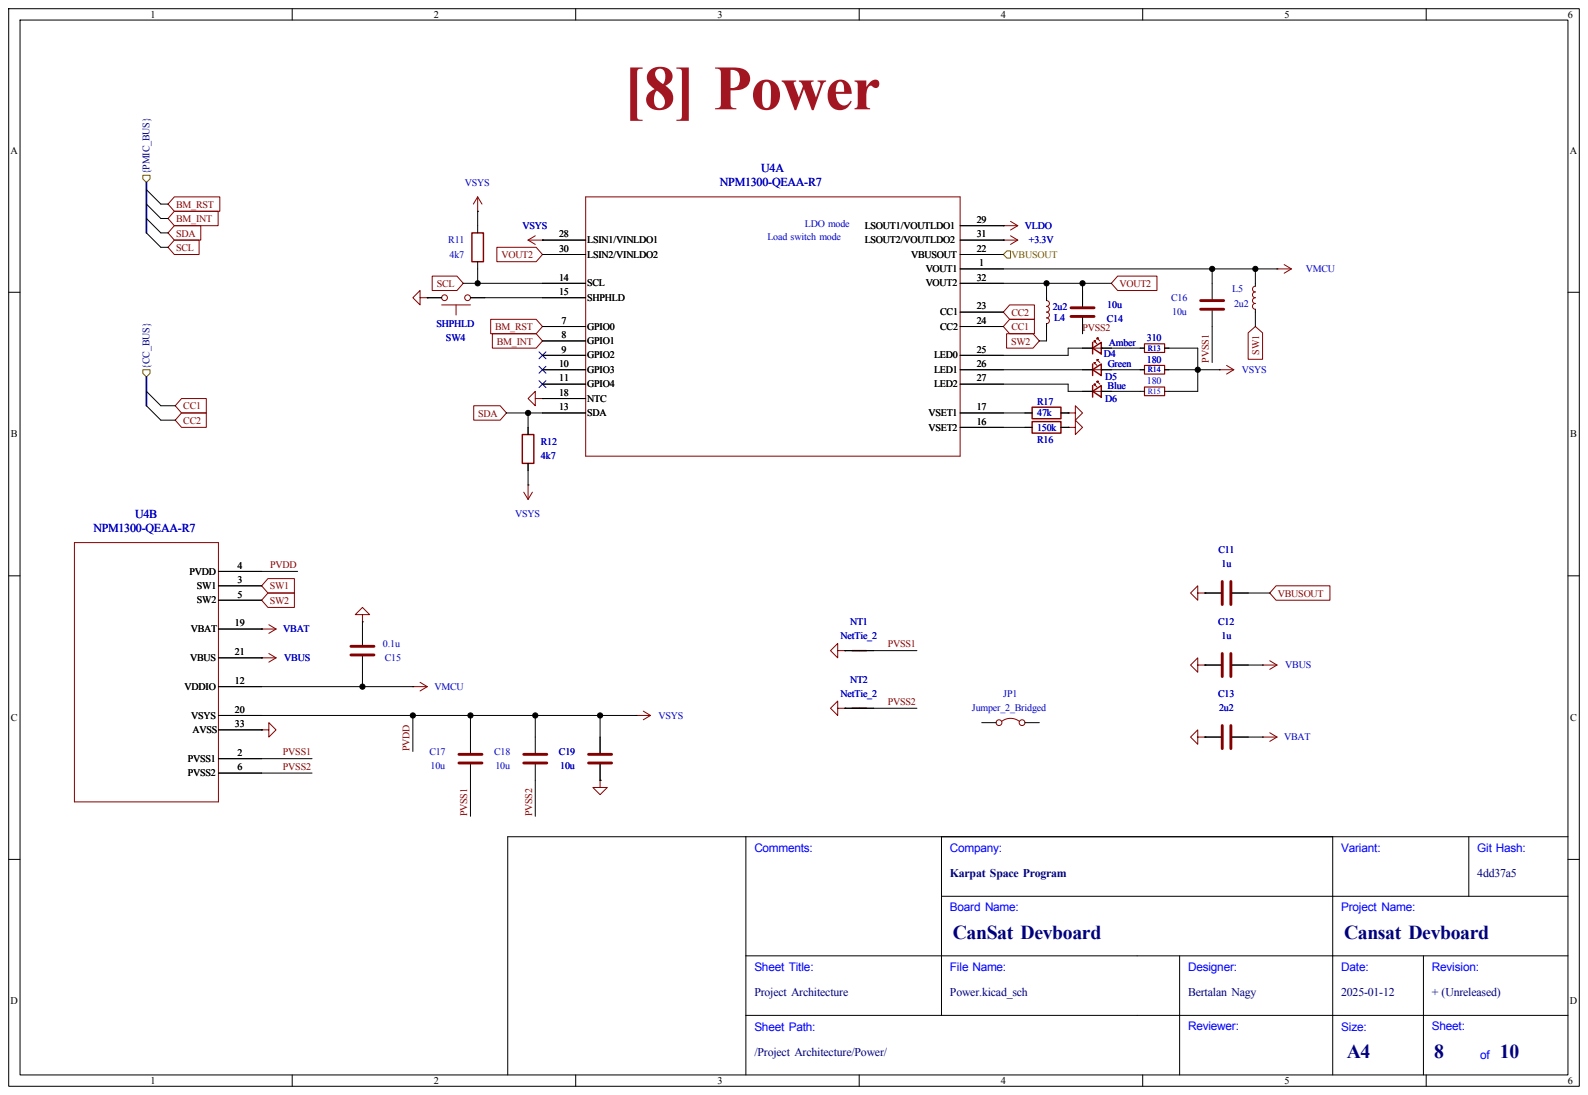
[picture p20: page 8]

LDO mode Load switch mode R12

Revision: + (Unreleased) Date: Project Name: 2025-01-12 Reviewer: Designer:


Revision: + (Unreleased) Date: Project Name: 2025-01-12 Reviewer: Designer:

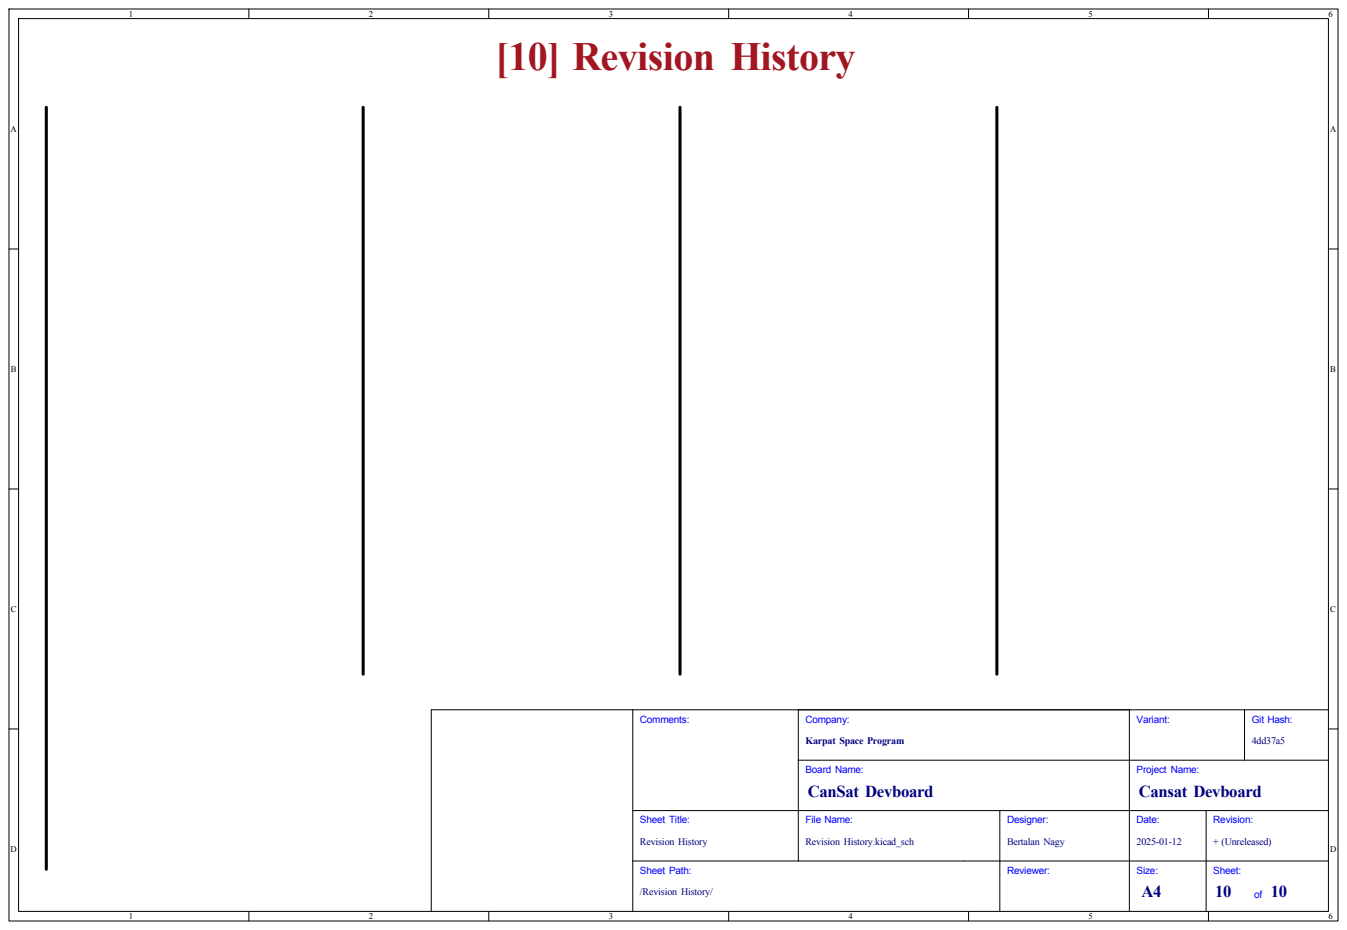
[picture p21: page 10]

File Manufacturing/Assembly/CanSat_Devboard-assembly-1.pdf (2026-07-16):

# CanSat Devboard Assembly Document

Git; Hash:; e9cdcd6; Comments:; Sheet Path:; Sheet Title:; File Name:; CanSat Devboard; Cansat Devboard; Company:; CHECKED; Variant:; Board Name:; CanSat_Devboard.kicad_pcb; Bertalan Nagy; Designer:; Reviewer:; Project Name:; Date:; + (Unreleased); Revision:; Size:; Sheet: 1

Karpat Space Program

Top/Bottom View

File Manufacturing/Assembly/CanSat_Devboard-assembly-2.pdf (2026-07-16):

# Top Assembly (Scale 1:1)

# CanSat Devboard Assembly Document


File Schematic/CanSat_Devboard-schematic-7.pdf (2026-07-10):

RST | [7] Misc

# 2 SW1 SW_Push SW2 RST


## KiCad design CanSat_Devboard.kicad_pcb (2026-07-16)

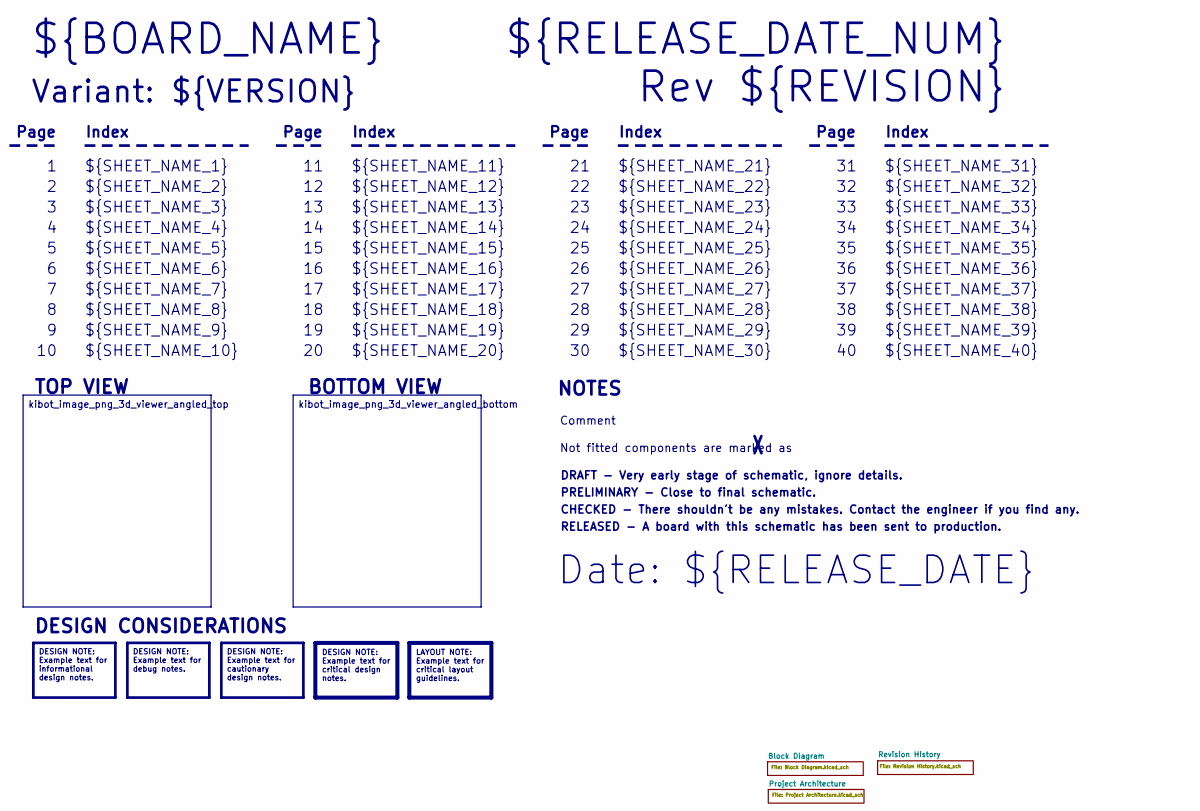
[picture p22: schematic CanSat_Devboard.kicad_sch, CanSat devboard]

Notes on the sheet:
Variant: ${VERSION}
RELEASED - A board with this schematic has been sent to production.
${SHEET_NAME_24}
Index
Page
PRELIMINARY - Close to final schematic.
${SHEET_NAME_22}
DRAFT - Very early stage of schematic, ignore details.
${SHEET_NAME_12}
${SHEET_NAME_8}
${SHEET_NAME_2}
${SHEET_NAME_5}
${SHEET_NAME_20}
${SHEET_NAME_23}
${RELEASE_DATE_NUM}
${SHEET_NAME_35}
Not fitted components are marked as
${SHEET_NAME_11}
${SHEET_NAME_6}
${SHEET_NAME_37}
${SHEET_NAME_26}
${SHEET_NAME_36}
Rev ${REVISION}
${SHEET_NAME_15}
CHECKED - There shouldn't be any mistakes. Contact the engineer if you find any.
BOTTOM VIEW
${SHEET_NAME_14}
${SHEET_NAME_21}
${SHEET_NAME_17}
${SHEET_NAME_18}
Date: ${RELEASE_DATE}
${SHEET_NAME_7}
${SHEET_NAME_31}
${BOARD_NAME}
NOTES
${SHEET_NAME_40}
${SHEET_NAME_39}
${SHEET_NAME_32}
${SHEET_NAME_1}
${SHEET_NAME_9}

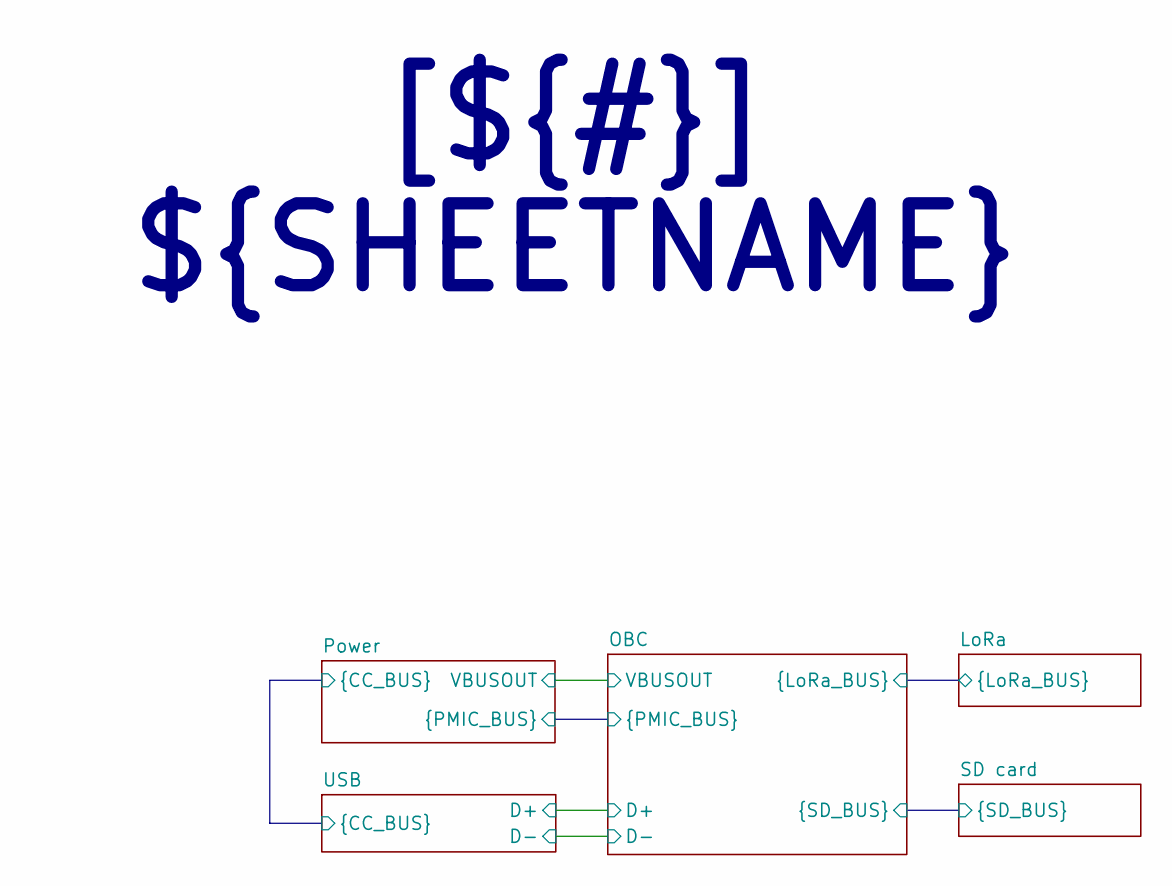
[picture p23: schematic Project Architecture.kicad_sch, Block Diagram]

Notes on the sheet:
[${#}] ${SHEETNAME}

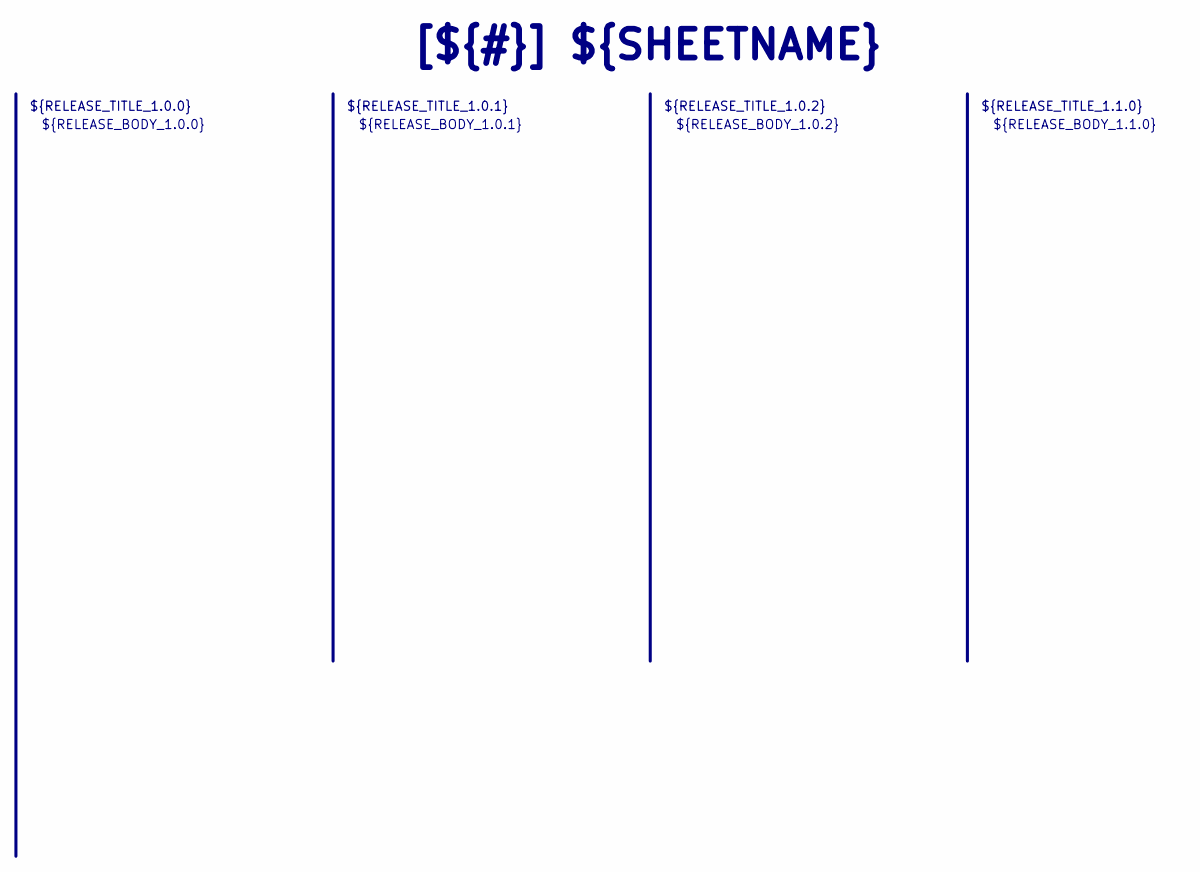
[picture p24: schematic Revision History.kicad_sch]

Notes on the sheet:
${RELEASE_BODY_1.0.1}
[${#}] ${SHEETNAME}
${RELEASE_BODY_1.0.2}
${RELEASE_TITLE_1.0.0}
${RELEASE_TITLE_1.0.1}
${RELEASE_BODY_1.0.0}
${RELEASE_BODY_1.1.0}
${RELEASE_TITLE_1.1.0}
${RELEASE_TITLE_1.0.2}

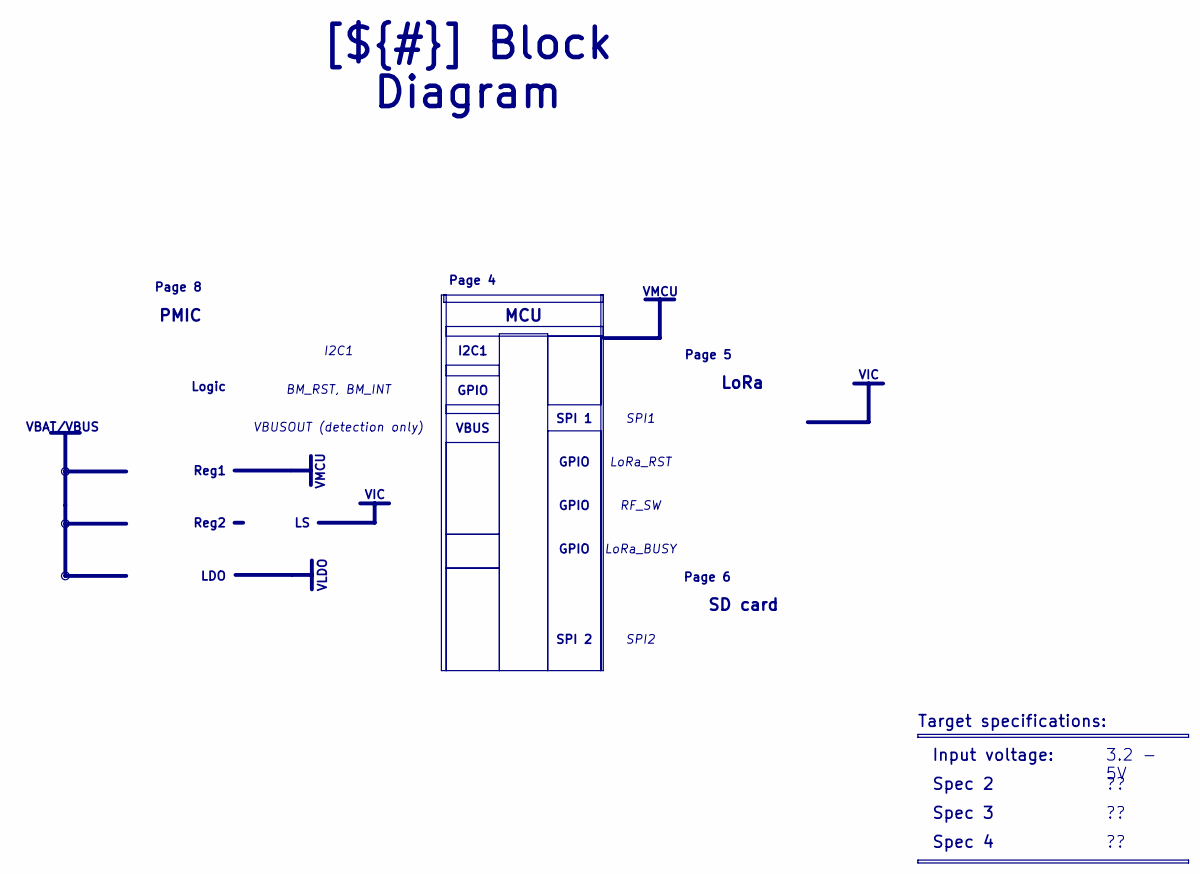
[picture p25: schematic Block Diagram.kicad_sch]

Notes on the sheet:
VIC
VBAT/VBUS
VMCU
VLDO
LoRa
Spec 4
Reg1
Reg2
3.2 - 5V
VBUSOUT (detection only)
MCU
GPIO
SPI1
Page 8
SPI2
SPI 2
SD card
LoRa_BUSY
I2C1
RF_SW
[${#}] ${TITLE}
Input voltage:
PMIC
Page 6
Target specifications:
VBUS
LDO
SPI 1
BM_RST, BM_INT
Spec 3
Spec 2
LoRa_RST
Logic
Page 4
Page 5

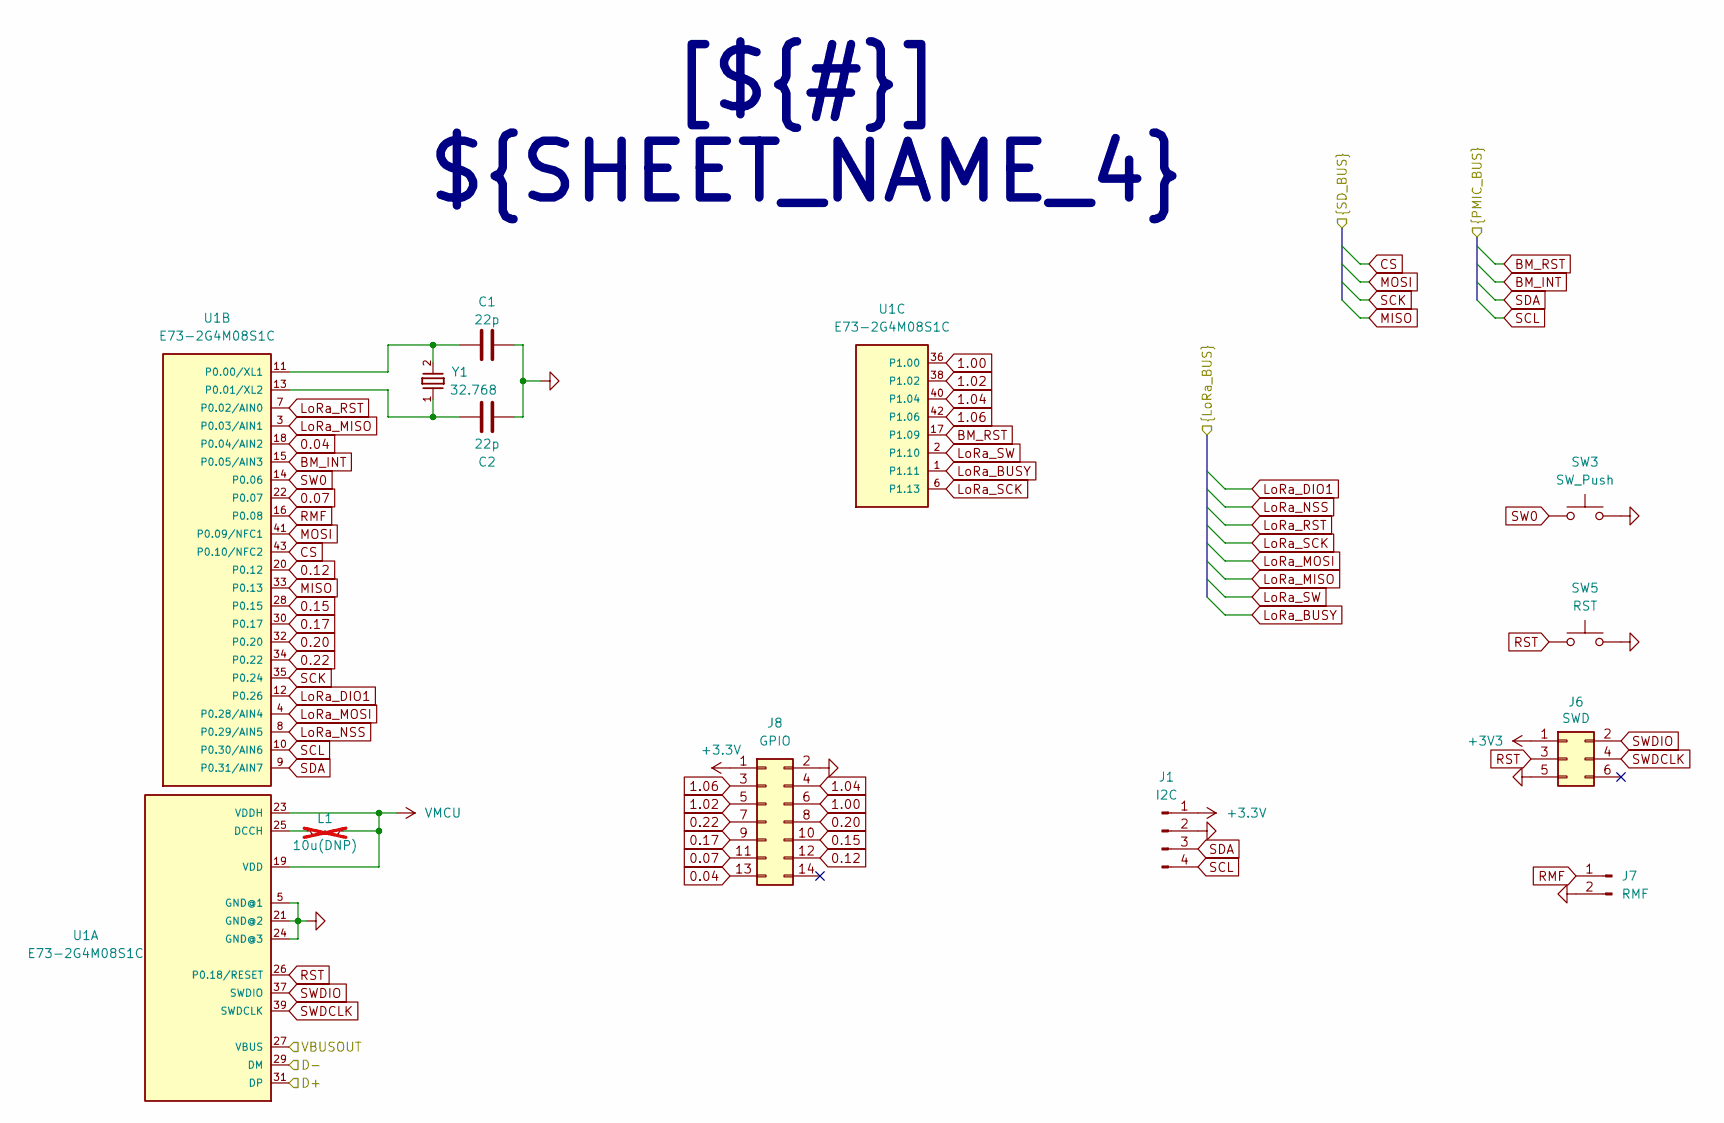
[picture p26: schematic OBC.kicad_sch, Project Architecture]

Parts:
C1, C2: 22p; C_0603_1608Metric
J1: I2C; PinHeader_1x04_P2.54mm_Vertical
J6: SWD; PinHeader_2x03_P2.54mm_Vertical
J7: RMF; PinHeader_1x02_P2.54mm_Vertical
J8: GPIO; PinHeader_2x07_P2.54mm_Vertical
L1: 10u(DNP); L_1210_3225Metric; not fitted
SW3: SW_Push; SW_Push_1P1T_NO_CK_KMR2
SW5: RST; SW_Push_1P1T_NO_CK_KMR2
U1: E73-2G4M08S1C
Y1: 32.768; WE-XTAL_CFPX-217

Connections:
0.04: J8.13, U1.18 (P0.04/AIN2)
0.07: J8.11, U1.22 (P0.07)
0.12: J8.12, U1.20 (P0.12)
0.15: J8.10, U1.28 (P0.15)
0.17: J8.9, U1.30 (P0.17)
0.20: J8.8, U1.32 (P0.20)
0.22: J8.7, U1.34 (P0.22)
1.00: J8.6, U1.36 (P1.00)
1.02: J8.5, U1.38 (P1.02)
1.04: J8.4, U1.40 (P1.04)
1.06: J8.3, U1.42 (P1.06)
+3.3V: J1.1, J8.1; also elsewhere on the board
+3V3: J6.1
/Project Architecture/OBC/D+: U1.31 (DP); also elsewhere on the board
/Project Architecture/OBC/D-: U1.29 (DM); also elsewhere on the board
BM_INT: U1.15 (P0.05/AIN3); also elsewhere on the board
BM_RST: U1.17 (P1.09); also elsewhere on the board
CS: U1.43 (P0.10/NFC2); also elsewhere on the board
GND: C1.1, C2.1, J1.2, J6.5, J7.2, J8.2, SW3.2, SW5.2, U1.5 (GND@1), U1.21 (GND@2), U1.24 (GND@3); also elsewhere on the board
LoRa_BUSY: U1.1 (P1.11); also elsewhere on the board
LoRa_DIO1: U1.12 (P0.26); also elsewhere on the board
LoRa_MISO: U1.3 (P0.03/AIN1); also elsewhere on the board
LoRa_MOSI: U1.4 (P0.28/AIN4); also elsewhere on the board
LoRa_NSS: U1.8 (P0.29/AIN5); also elsewhere on the board
LoRa_RST: U1.7 (P0.02/AIN0); also elsewhere on the board
LoRa_SCK: U1.6 (P1.13); also elsewhere on the board
LoRa_SW: U1.2 (P1.10); also elsewhere on the board
MISO: U1.33 (P0.13); also elsewhere on the board
MOSI: U1.41 (P0.09/NFC1); also elsewhere on the board
unnamed: L1.1, U1.25 (DCCH)
unnamed: C1.2, U1.11 (P0.00/XL1), Y1.2
unnamed: C2.2, U1.13 (P0.01/XL2), Y1.1
RMF: J7.1, U1.16 (P0.08)
RST: J6.3, SW5.1, U1.26 (P0.18/RESET)
SCK: U1.35 (P0.24); also elsewhere on the board
SCL: J1.4, U1.10 (P0.30/AIN6); also elsewhere on the board
SDA: J1.3, U1.9 (P0.31/AIN7); also elsewhere on the board
SW0: SW3.1, U1.14 (P0.06)
SWDCLK: J6.4, U1.39 (SWDCLK)
SWDIO: J6.2, U1.37 (SWDIO)
VBUSOUT: U1.27 (VBUS); also elsewhere on the board
VMCU: L1.2, U1.19 (VDD), U1.23 (VDDH); also elsewhere on the board

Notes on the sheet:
[${#}] ${SHEET_NAME_4}

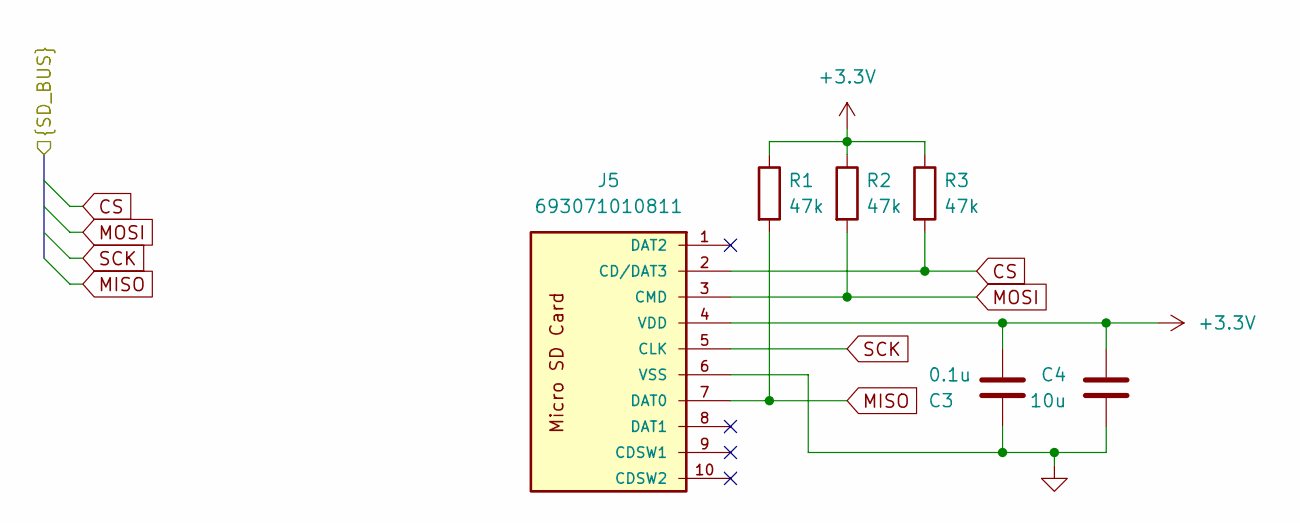
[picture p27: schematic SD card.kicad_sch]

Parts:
C3: 0.1u; C_0603_1608Metric
C4: 10u; C_0603_1608Metric
J5: 693071010811
R1, R2, R3: 47k; R_0603_1608Metric

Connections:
+3.3V: C3.2, C4.2, J5.4 (VDD), R1.1, R2.1, R3.1; also elsewhere on the board
CS: J5.2 (CD/DAT3), R3.2; also elsewhere on the board
GND: C3.1, C4.1, J5.6 (VSS); also elsewhere on the board
MISO: J5.7 (DAT0), R1.2; also elsewhere on the board
MOSI: J5.3 (CMD), R2.2; also elsewhere on the board
SCK: J5.5 (CLK); also elsewhere on the board

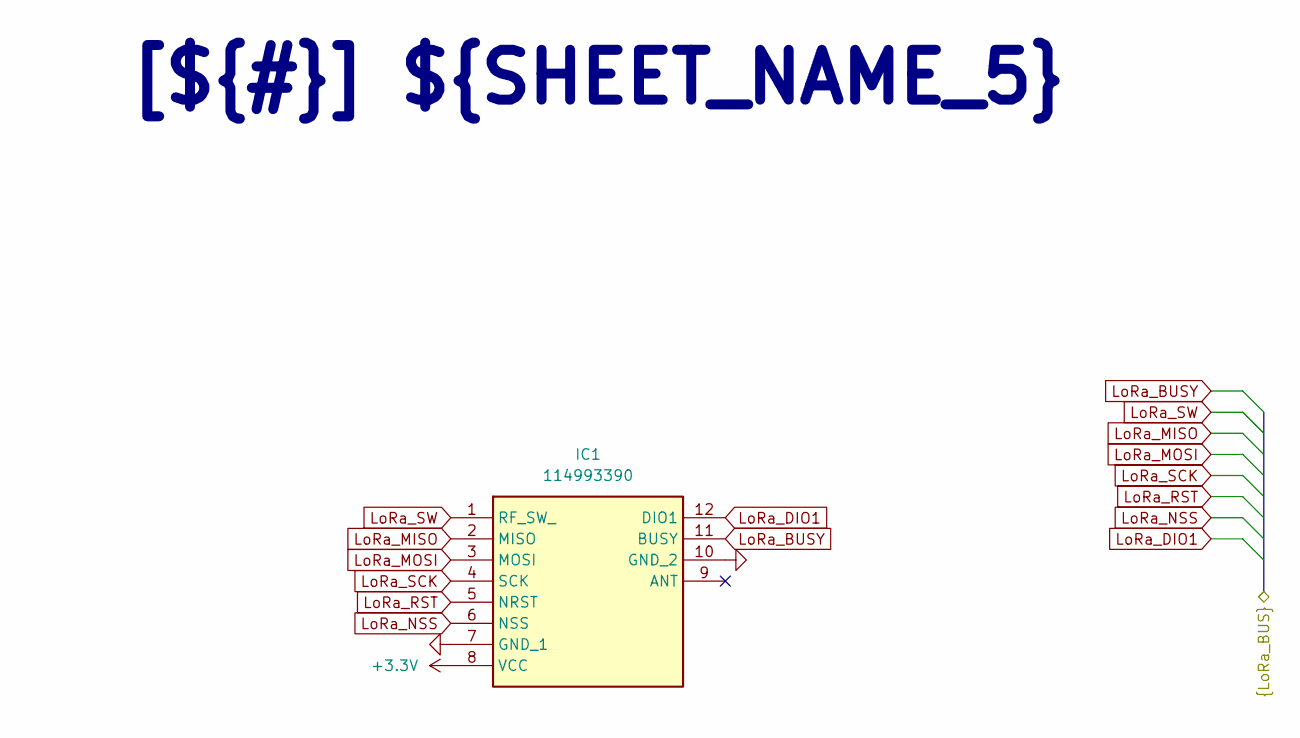
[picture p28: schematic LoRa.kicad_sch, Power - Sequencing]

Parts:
IC1: 114993390; Mouser Part Number 713-114993390

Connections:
+3.3V: IC1.8 (VCC); also elsewhere on the board
GND: IC1.7 (GND_1), IC1.10 (GND_2); also elsewhere on the board
LoRa_BUSY: IC1.11 (BUSY); also elsewhere on the board
LoRa_DIO1: IC1.12 (DIO1); also elsewhere on the board
LoRa_MISO: IC1.2 (MISO); also elsewhere on the board
LoRa_MOSI: IC1.3 (MOSI); also elsewhere on the board
LoRa_NSS: IC1.6 (NSS); also elsewhere on the board
LoRa_RST: IC1.5 (NRST); also elsewhere on the board
LoRa_SCK: IC1.4 (SCK); also elsewhere on the board
LoRa_SW: IC1.1 (RF_SW_); also elsewhere on the board

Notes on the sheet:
[${#}] ${SHEET_NAME_5}

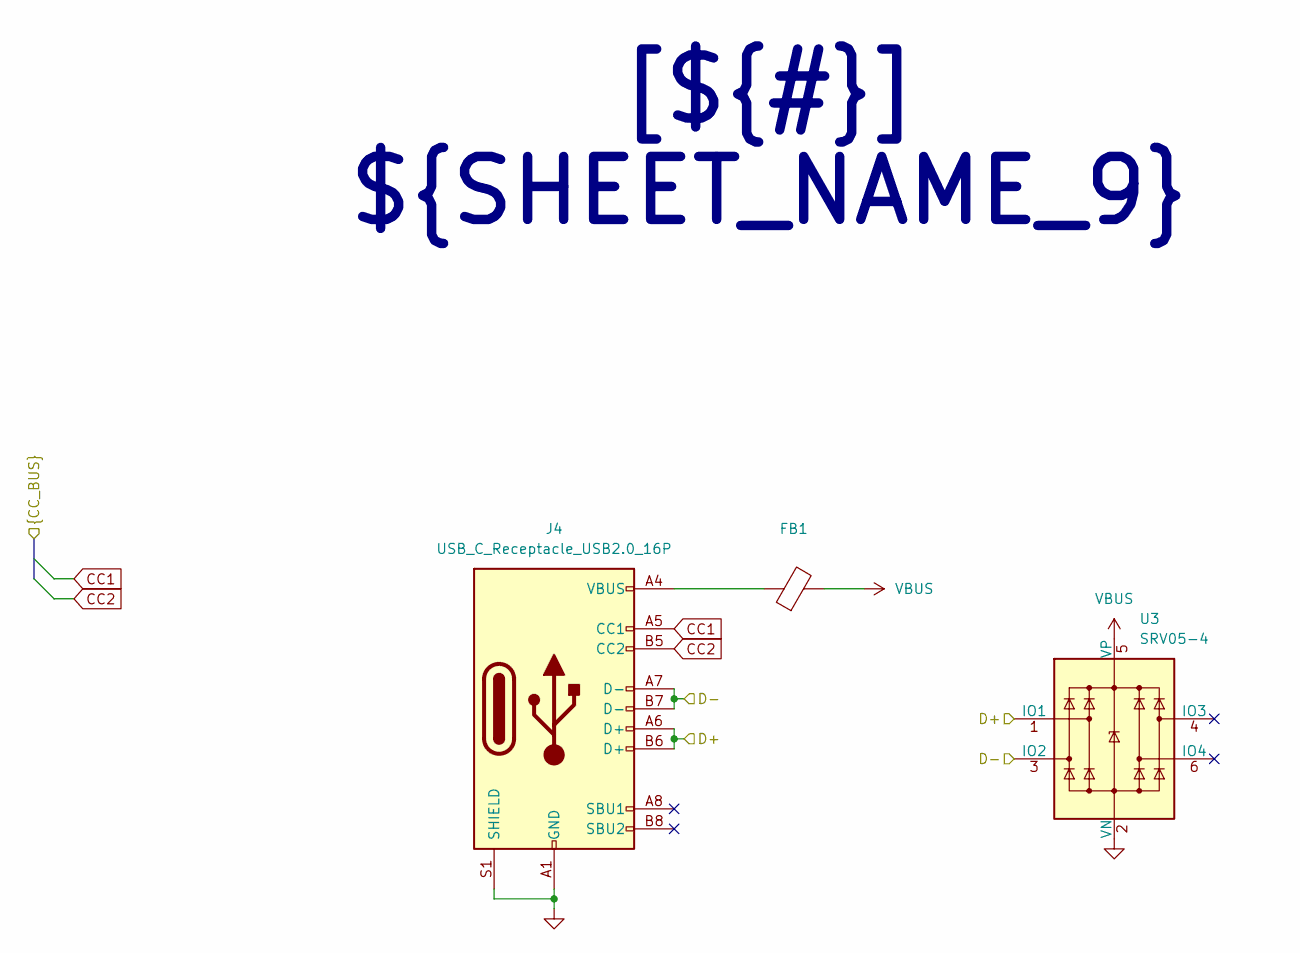
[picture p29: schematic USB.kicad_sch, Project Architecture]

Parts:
FB1: LI0603G121R-10; L_0603_1608Metric
J4: USB_C_Receptacle_USB2.0_16P; USB_C_Receptacle_GCT_USB4105-xx-A_16P_TopMnt_Horizontal
U3: SRV05-4; SOT-23-6_Handsoldering

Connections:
/Project Architecture/OBC/D+: J4.A6 (D+), J4.B6 (D+), U3.1 (IO1); also elsewhere on the board
/Project Architecture/OBC/D-: J4.A7 (D-), J4.B7 (D-), U3.3 (IO2); also elsewhere on the board
CC1: J4.A5 (CC1); also elsewhere on the board
CC2: J4.B5 (CC2); also elsewhere on the board
GND: J4.A1 (GND), J4.A12 (GND), J4.B1 (GND), J4.B12 (GND), J4.S1 (SHIELD), U3.2 (VN); also elsewhere on the board
unnamed: FB1.1, J4.A4 (VBUS), J4.A9 (VBUS), J4.B4 (VBUS), J4.B9 (VBUS)
VBUS: FB1.2, U3.5 (VP); also elsewhere on the board

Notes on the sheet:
[${#}] ${SHEET_NAME_9}

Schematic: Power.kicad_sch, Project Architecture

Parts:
C11, C12: 1u; C_0603_1608Metric
C13: 2u2; C_0603_1608Metric
C14, C16, C17, C18, C19: 10u; C_0603_1608Metric
C15: 0.1u; C_0603_1608Metric
D4: Amber; LED_0603_1608Metric
D5: Green; LED_0603_1608Metric
D6: Blue; LED_0603_1608Metric
J3: Conn_01x03_Pin; JST_XH_B3B-XH-A_1x03_P2.50mm_Vertical
L4, L5: 2u2; L_1812_4532Metric
R11, R12: 4k7; R_0603_1608Metric
R13: 310; R_0603_1608Metric
R14, R15: 180; R_0603_1608Metric
R16: 150k; R_0603_1608Metric
R17: 47k; R_0603_1608Metric
SW4: SHPHLD; SW_Push_1P1T_NO_CK_KMR2
TP7: VMCU; TestPoint_Pad_D1.0mm
TP8: VSYS; TestPoint_Pad_D1.0mm
TP9: 3V3; TestPoint_Pad_D1.0mm
TP10: VLDO; TestPoint_Pad_D1.0mm
U4: NPM1300-QEAA-R7; QFN32_5X5_NOR

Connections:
+3.3V: TP9.1 (1_1), U4.31 (LSOUT2/VOUTLDO2); also elsewhere on the board
BM_INT: U4.8 (GPIO1); also elsewhere on the board
BM_RST: U4.7 (GPIO0); also elsewhere on the board
CC1: U4.23 (CC1); also elsewhere on the board
CC2: U4.24 (CC2); also elsewhere on the board
GND: C11.1, C12.1, C13.1, C14.2, C15.2, C16.1, C17.1, C18.1, C19.1, J3.2, R16.2, R17.2, SW4.2, U4.2 (PVSS1), U4.6 (PVSS2), U4.33 (AVSS); also elsewhere on the board
NTC: J3.1, U4.18 (NTC)
unnamed: D4.2 (A), R13.1
unnamed: D4.1 (K), U4.25 (LED0)
unnamed: D5.2 (A), R14.1
unnamed: D5.1 (K), U4.26 (LED1)
unnamed: D6.2 (A), R15.1
unnamed: D6.1 (K), U4.27 (LED2)
unnamed: SW4.1, U4.15 (SHPHLD)
unnamed: R17.1, U4.17 (VSET1)
unnamed: R16.1, U4.16 (VSET2)
SCL: R11.2, U4.14 (SCL); also elsewhere on the board
SDA: R12.1, U4.13 (SDA); also elsewhere on the board
SW1: L5.1, U4.3 (SW1)
SW2: L4.2, U4.5 (SW2)
VBAT: C13.2, J3.3, U4.19 (VBAT)
VBUS: C12.2, U4.21 (VBUS); also elsewhere on the board
VBUSOUT: C11.2, U4.22 (VBUSOUT); also elsewhere on the board
VLDO: TP10.1 (1_1), U4.29 (LSOUT1/VOUTLDO1)
VMCU: C15.1, C16.2, L5.2, R11.1, R12.2, TP7.1 (1_1), U4.1 (VOUT1), U4.12 (VDDIO); also elsewhere on the board
VOUT2: C14.1, L4.1, U4.30 (LSIN2/VINLDO2), U4.32 (VOUT2)
VSYS: C17.2, C18.2, C19.2, R13.2, R14.2, R15.2, TP8.1 (1_1), U4.4 (PVDD), U4.20 (VSYS), U4.28 (LSIN1/VINLDO1)

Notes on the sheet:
LDO mode
Load switch mode
[${#}] ${SHEET_NAME_8}

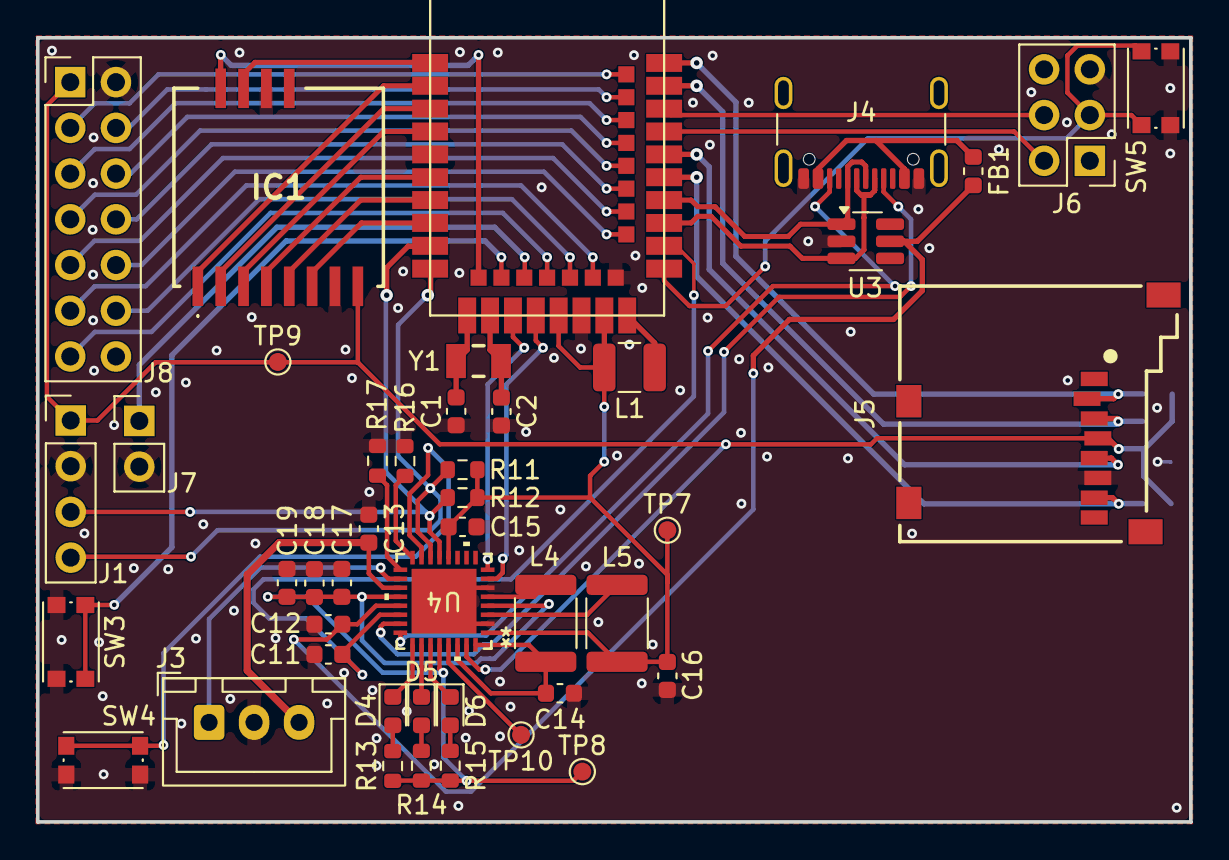
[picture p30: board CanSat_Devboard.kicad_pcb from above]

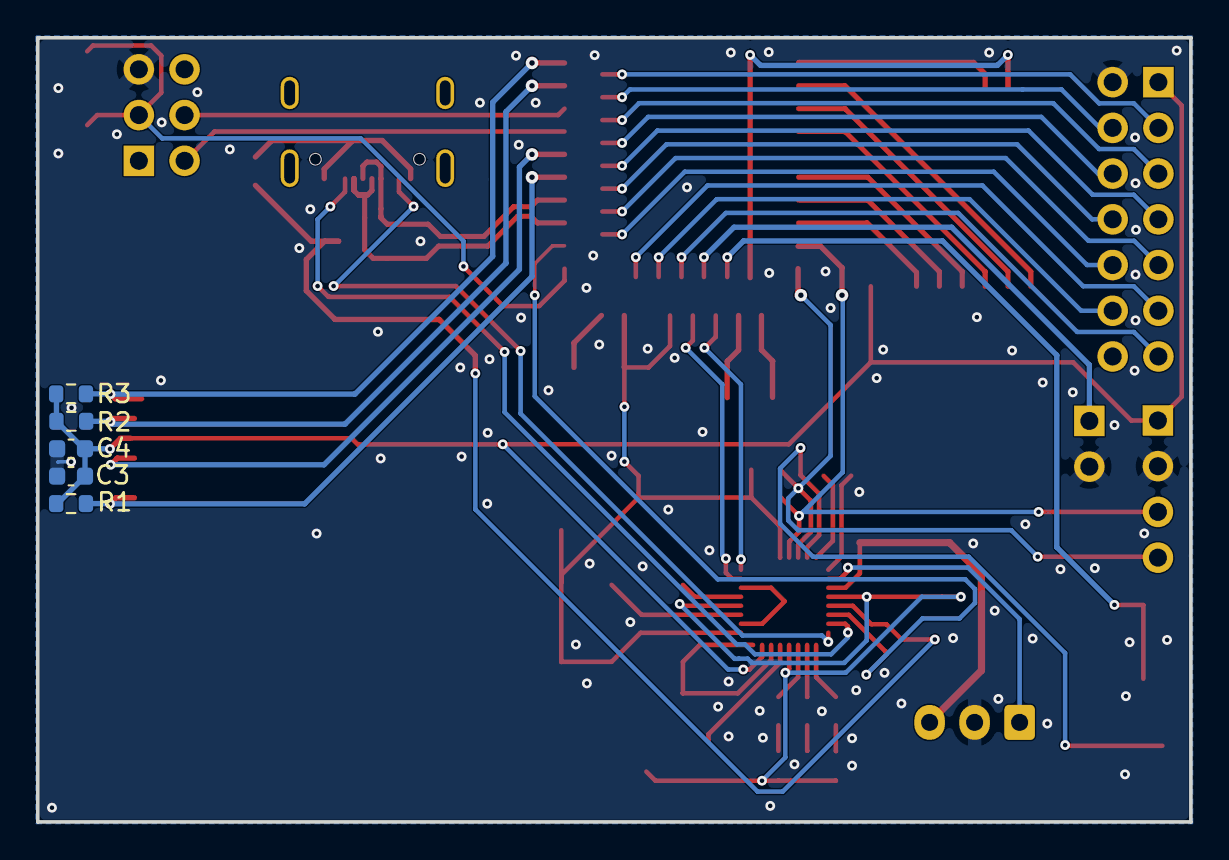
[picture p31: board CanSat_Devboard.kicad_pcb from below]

Board: 4 copper layers, 64.1 x 43.6 mm, 49 parts (5 on the bottom side), 61 nets.

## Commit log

2026-07-05 Started block diagram design
    [Block Diagram.kicad_sch, CanSat_Devboard.kicad_sch, Power - Sequencing.kicad_sch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]
2026-07-05 Organized schematic pages
    [Block Diagram.kicad_sch, CanSat_Devboard.kicad_sch, LoRa.kicad_sch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]
2026-07-05 Update README with CanSat project details
    Added a new section for a CanSat project development board and updated the README structure.
2026-07-06 Pasted schematics from previous design
    [CanSat_Devboard.kicad_sch, LoRa.kicad_sch, Misc.kicad_sch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]
2026-07-06 Changed a few preferences
    [CanSat_Devboard.kicad_sch, OBC.kicad_sch, Power.kicad_sch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]
2026-07-08 Finished preliminary project schematics and architecture
    [Block Diagram.kicad_sch, CanSat_Devboard.kicad_pcb, CanSat_Devboard.kicad_sch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]
2026-07-09 Added new lora module library zip
    [Project Architecture.kicad_sch, SD_card.kicad_sch]
2026-07-09 Edited ci.yaml
    [CanSat_Devboard.kicad_pcb, Misc.kicad_sch, OBC.kicad_sch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]
2026-07-09 Update Outputs
    [CanSat_Devboard-(L1-L6)_NPTH_drill_table.csv, CanSat_Devboard-(L1-L6)_drill_table.csv, CanSat_Devboard-components_count.csv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]
2026-07-09 Cleaned up
    [CanSat_Devboard.kicad_pcb, LoRa.kicad_sch, Misc.kicad_sch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]
2026-07-10 Minor schematic adjustments
    [Block Diagram.kicad_sch, LoRa.kicad_sch, Misc.kicad_sch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]
2026-07-10 Minor tweaks
    [Power.kicad_sch]
2026-07-10 Updated layout with the footprints
    [CanSat_Devboard.kicad_pcb]
2026-07-10 Finalized schematic
    [OBC.kicad_sch, Power.kicad_sch, Project Architecture.kicad_sch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]
2026-07-10 Started PCB layout
    [CanSat_Devboard.kicad_pcb, OBC.kicad_sch, Power.kicad_sch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]
2026-07-10 Started layout
    [CanSat_Devboard.kicad_pcb, OBC.kicad_sch, USB.kicad_sch]
2026-07-11 Continued layout and routing
    [CanSat_Devboard.kicad_pcb, OBC.kicad_sch, Power.kicad_sch]
2026-07-11 Finished PCB design
    [CanSat_Devboard.kicad_pcb, OBC.kicad_sch]
2026-07-11 Fixed 3d models
    [CanSat_Devboard.kicad_pcb]
2026-07-11 Reloading 3d render
    [CanSat_Devboard-(L1-L4)_NPTH_drill_table.csv, CanSat_Devboard-(L1-L4)_drill_table.csv, CanSat_Devboard-(L1-L6)_NPTH_drill_table.csv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]
2026-07-11 3D fixes
    [CanSat_Devboard.kicad_pcb]
2026-07-12 Flipped SD card slot
    [CanSat_Devboard.kicad_pcb, OBC.kicad_sch]
2026-07-13 Connected DIO1 of lora module
    [CanSat_Devboard.kicad_pcb, LoRa.kicad_sch, OBC.kicad_sch]
2026-07-13 Changed design stage to CHECKED
2026-07-13 Fixed ERC errors
    [OBC.kicad_sch]
2026-07-16 Fixed a roouting mistake
    [CanSat_Devboard.kicad_pcb, Power.kicad_sch]
